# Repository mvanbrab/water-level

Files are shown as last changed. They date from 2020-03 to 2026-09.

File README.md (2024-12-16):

# Introduction
Here I share hardware and software about my **water-level** project,
whose purpose is to measure the water level in a water reservoir,
located under the ground.

This project actually has a predecessor. Enjoy reading about it in this [bit of history](doc/history.md).

# The transmitter
The first piece of hardware is a transmitter.
It measures the water level with a waterproof ultrasonic sensor and sends the measurement result as a JSON object via RS232 to a possibly connected receiver.

The positioning of this sensor in my project is described in the [physical setup](doc/physical.md).

Here are some [pictures](doc/pictures-transmitter.md) showing the transmitter in practice.

In the folder **hardware/transmitter** you'll find the hardware design as a [KiCad](https://www.kicad.org/) project.
Without Kicad installed, you can view
- [the schematic diagram as .pdf](../master/hardware/transmitter.pdf);
- [the copper layout of the printed circuit board](../master/hardware/transmitter_cu.pdf);
- [the component placement on the printed circuit board](../master/hardware/transmitter_silk.pdf).

The folder **software/WaterLevelTransmitter** is an [Arduino](https://www.arduino.cc/) sketch, containing the software of the transmitter part of the project.

Read more about this piece of software [here](doc/water-level-transmitter-software.md).

# The receiver
The second piece of hardware is the receiver.
It requests output from the transmitter and publishes is to whatever destination.

Here are some [pictures](doc/pictures-receiver.md) showing the receiver in practice.

In the folder **hardware/receiver** you'll find the hardware design as a [KiCad](https://www.kicad.org/) project.
Without Kicad installed, you can view
- [the schematic diagram as .pdf](../master/hardware/receiver.pdf);
- [the copper layout of the printed circuit board](../master/hardware/receiver_cu.pdf);
- [the component placement on the printed circuit board](../master/hardware/receiver_silk.pdf).

About the receiver hardware:
- the RS232 level converter is the same as used for the transmitter, this time it is powered from 3V3;
- the character-based LCD screen to connect is a 2 rows of 16 columns type, using an HD44780 driver, connected via I2C @ 3V3, but powered @ 5V;
- the processor board (chosen because of its WiFi connectivity) is a [ESP32 DevKitC](https://docs.espressif.com/projects/esp-idf/en/latest/esp32/hw-reference/esp32/get-started-devkitc.html)
 (with ESP32-WROOM-32D module).

The folder **software/WaterLevelReceivers** is contains a set of [Arduino](https://www.arduino.cc/) sketches, each containing a different software solution for the receiver part of the project.

Read more about this piece of software [here](doc/water-level-receiver-software.md).

# Connecting the transmitter with the receiver

| Transmitter | Receiver |
| --- | --- |
| GND (J1.2)  | GND (J1.3) |
| TXD (J1.4)  | RXD (J1.2) |
| RXD (J1.5)  | TXD (J1.1) |

# Lessons learned
[The temperature measurement](doc/ll01.md)

[Condensation on the sensor](doc/ll02.md)

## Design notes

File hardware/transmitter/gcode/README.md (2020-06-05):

Files here were added by Dylan and are derived from the Kicad project, using his tools for pcb creation.

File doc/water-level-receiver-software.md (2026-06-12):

# The WaterLevelReceiver software

## Operation

Every second, the program sends a single "?" character to the Serial2 port, at 115200 Baud.
Each "?" acts as a request for a new measurement to the connected transmitter.
If all's well, the transmitter will reply with a JSON output as document in the [transmitter documentation](water-level-transmitter-software.md).

The receiver will decode this JSON payload and can publish it to several destinations,
depending on the version of the program.
The supported destinations:

- the serial port accessible through the USB connection (at 115200 Baud);
- a character-based LCD display using the hd44780 chip;
- a locally hosted webpage;
- MQTT, in this case to a topic "home/regenput/state".

In addition, the program watches button input.
Currently, there is only one button defined:

- a button connected between GPIO12 and ground: controls LCD backlight (button closed = backlight on).

## Serial port output

Serial port output consists of:

- the temperature in numerical form;
- the volume in liters in numerical form;
- the volume as percentage in numerical form;
- a LOW indicator, only written if the level is low.

## LCD output

LCD output consist of:

- a representation of the volume as percentage in a bar graph;
- the volume as percentage in numerical form;
- the volume in liters in numerical form;
- a LOW indicator, only displayed if the level is low;
- a heartbeat indicator, changing between '*' and ' '.

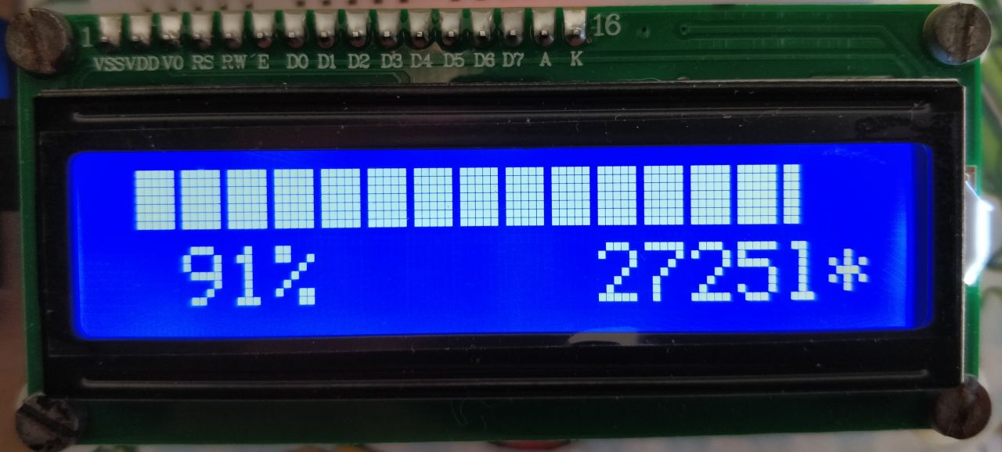
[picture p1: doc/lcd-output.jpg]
lcd-output


## HTTP output

HTTP output can consist of all information available in the serial port output.

Currently, a simple HTML representation shows:

- volume in liters, in a HTML meter element and as percentage (the LOW indicator is represented with red volume values) 
- temperature in °C (red in case of frost)

An example:

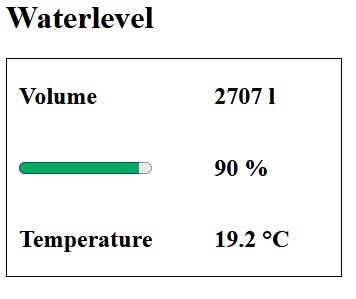
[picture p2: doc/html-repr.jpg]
html-representation


## MQTT output

An MQTT server is accessed via WiFi using the Arduino library 'EspMQTTClient'
and the output is published on a single topic "home/regenput/state" once per minute.

The payload is a JSON structure consisting of the fields:

- "t_C": the temperature;
- "vol_l": the volume in liters;
- "vol_percent": the volume as percentage;
- "low: the LOW indicator (true/false).

### Possibilities with MQTT

What follows is a non limiting list of examples.

#### Display data on Node-RED user interface elements

The Node-RED package `node-red-dashboard` has interesting nodes such as a **gauge**, allowing
to display output as shown below.

#### Export data to Influxdb for possible display using Grafana

The Node-RED contributed package `node-red-contrib-influxdb` has an **influxdb out** node, allowing to output data
to [Influxdb](https://www.influxdata.com/products/influxdb/).

These data can then be read by [Grafana](https://grafana.com/oss/), a great tool to visualise data.

#### Display the data in Home Assistant

For this purpose, the code publishes MQTT Discovery messages with single component discovery payload, understood by Home Assistant.

## Testing

Some DEBUG... preprocessor definitions are available to assist debugging the code.
They provide possibilities to output debug information and to provide fake input.

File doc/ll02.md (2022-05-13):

# Lesson learned: condensation on the sensor

## The problem

In november 2020 the measurement suddenly became unstable.

I had a look at the sensor and apparently there was so much condensation,
that some big drops of water where hanging at the bottom (active side) of the sensor.

Drying the sensor made the measurement stable again.

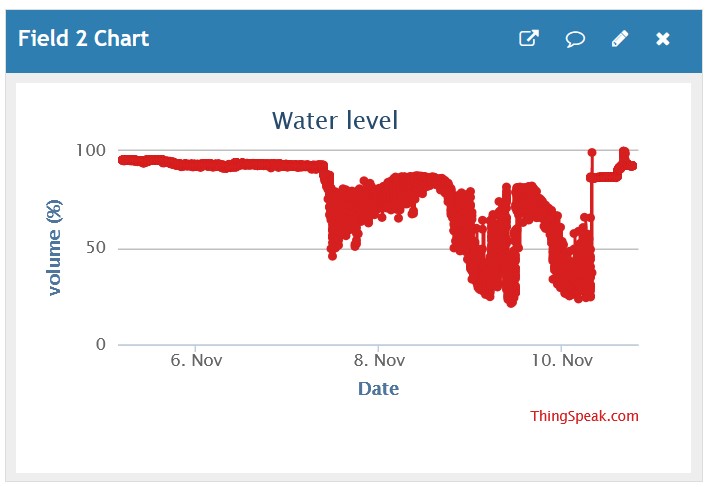
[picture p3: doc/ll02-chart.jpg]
chart


The reason for this condensation is obviously the combination of the following conditions:
* high vapor pressure
* bad ventilation
* cold sensor temperature 

## Attempt 1 (November 2020)

The idea behind this attempt is: give the water drops the possibility to drip off.

The sensor was rotated 90 degrees, putting the sensor surface vertically.
A reflection plate placed at 45 degrees ensures that the ultrasonic wave propagates in the correct direction.

As you can see, the mechanical setup reuses the original sensor mount.

Bottom view:

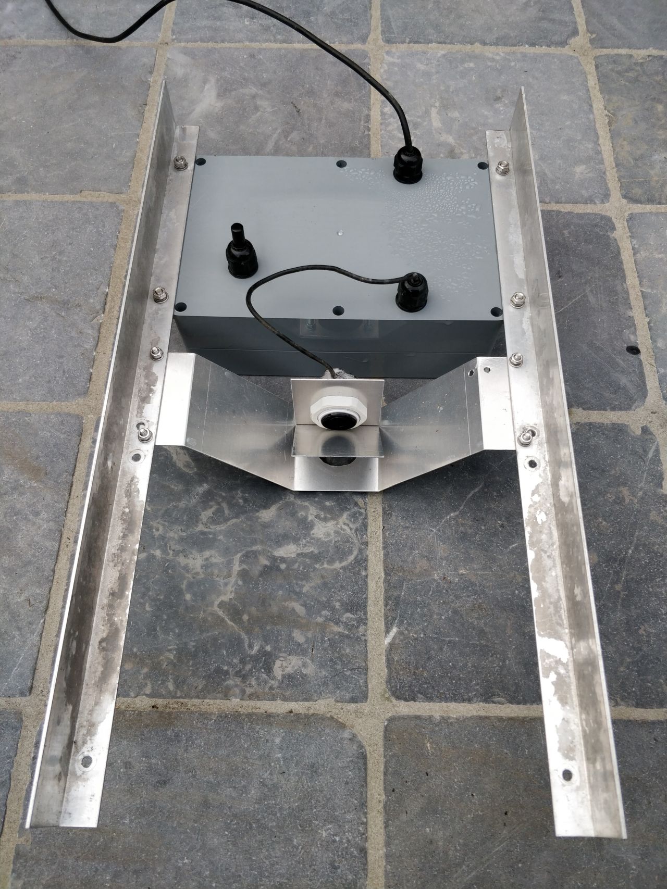
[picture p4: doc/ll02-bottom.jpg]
bottom


Detailed view:

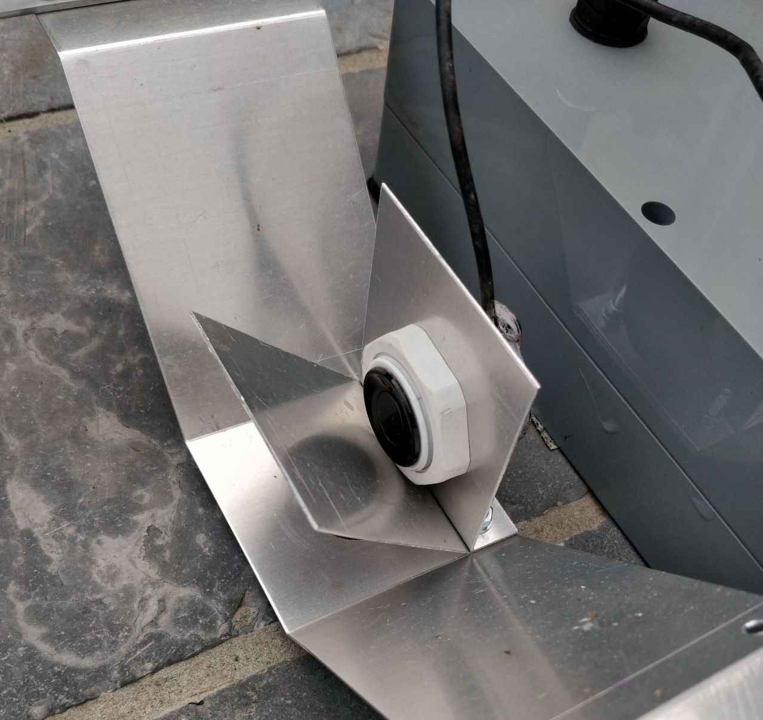
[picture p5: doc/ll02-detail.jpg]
detail


Installed:

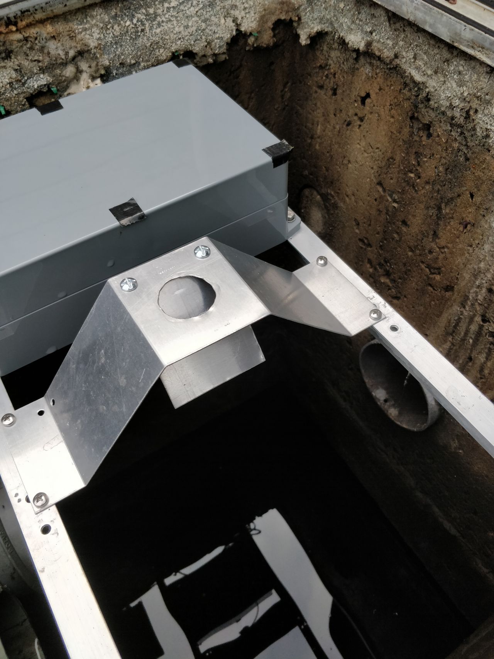
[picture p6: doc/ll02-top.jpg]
top


### Evaluation

The solution seemed to work well during winter.

However, due to frequent rainfall, the water level was continuously close to 100 %.

Around the middle of February, a dry period started end the water level started to fall.
The measurement however did not follow and somewhat later started to float heavily.

Inspection revealed that both the sensor and the reflection plate suffered from condensation again.
Drying them resulted in a stable measurement, until they suffered again from condensation later...

So clearly, this attempt is not a good solution

### Attempt 2 (March 2021)

The idea behind this attempt is: try to avoid low temperature at the sensor and the reflection plate, using isolation foam.

The sensor and the reflection plate were isolated as good as possible from the lid.

Sensor and reflection plate:

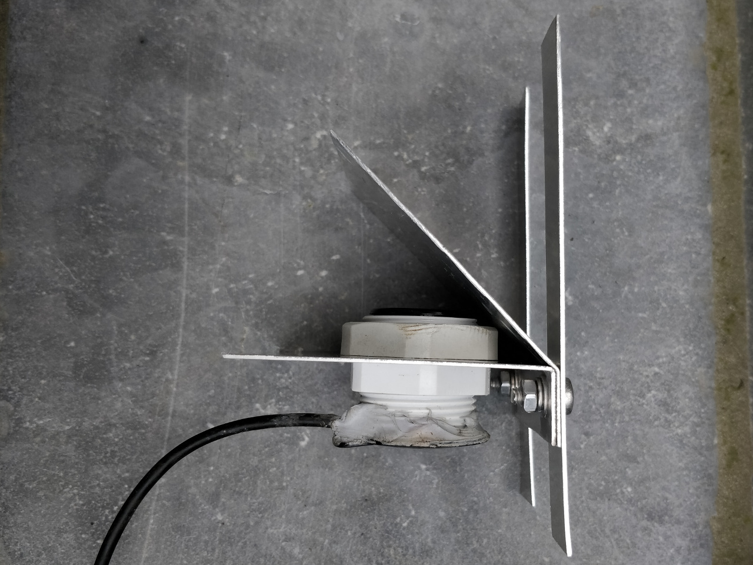
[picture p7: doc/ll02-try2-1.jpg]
attempt 2 sensor and reflection plate


Mounting in isolating box:

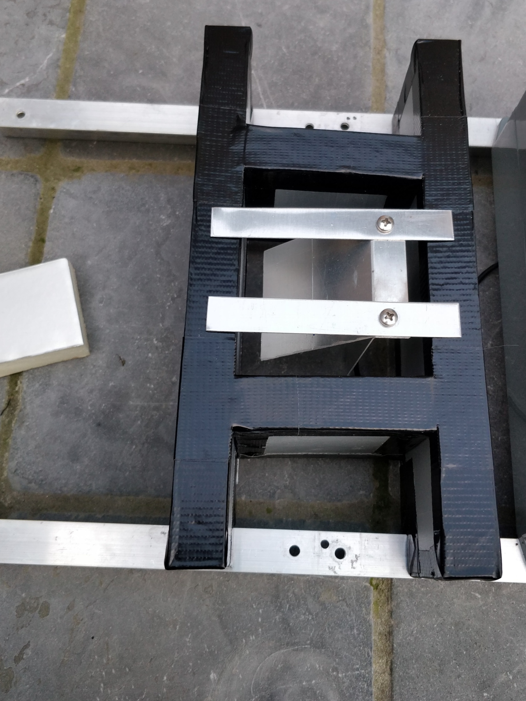
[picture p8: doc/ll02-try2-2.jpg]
attempt 2 mounting


Mounted:

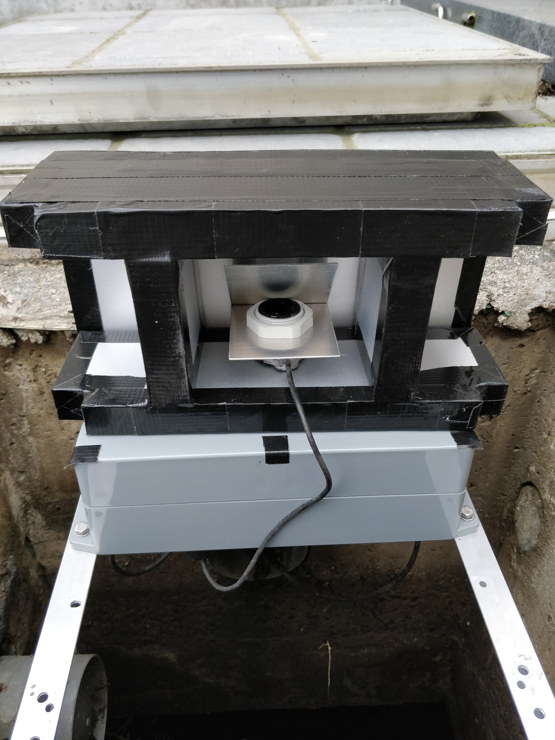
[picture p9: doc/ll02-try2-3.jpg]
attempt 2 mounted


Installed:

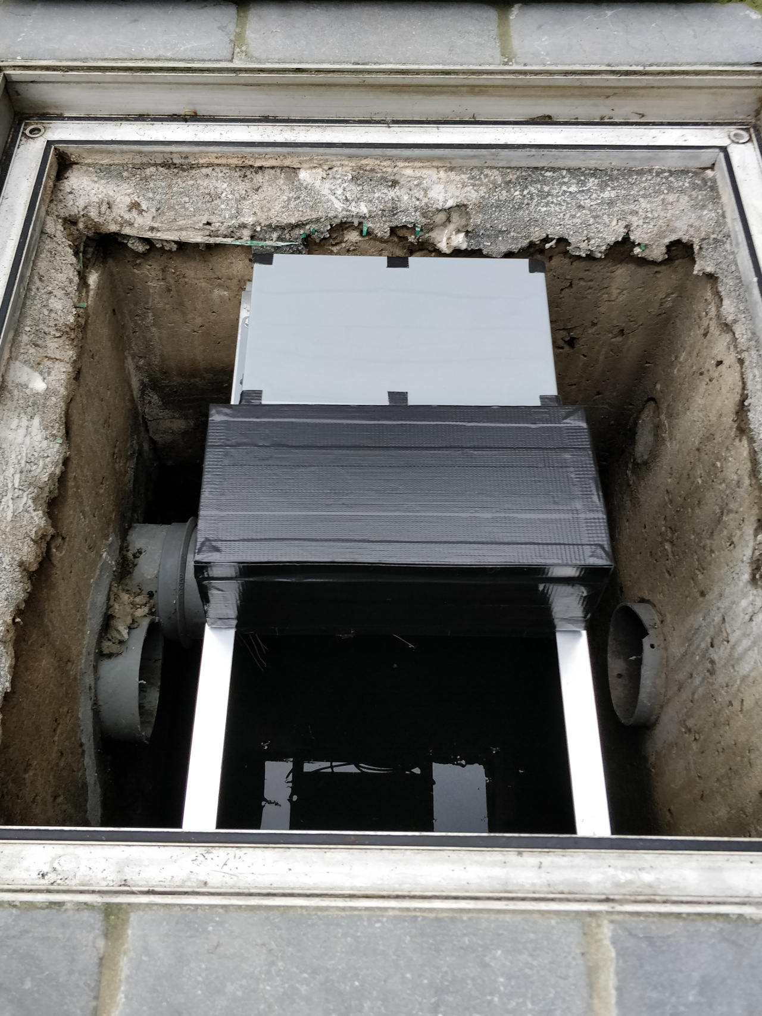
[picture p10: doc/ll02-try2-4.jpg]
attempt 2 installed


### Evaluation

The solution worked for a week, then: same problem. Changing weather conditions make it work well from time to time.
Drying sensor and reflection plate always helps instantaneously, but the problem keeps on returning...

### Attempt 3 (April 2021)

The input for this attempt is the observation that there is no condensation at the bottom of the plastic box.
Perhaps this is due to the small temperature rise due heat dissipation of the electronics.

The sensor was integrated in the bottom of the plastic box, and the voltage regulator (main source of dissipation)
was put on an aluminium frame, as close to the sensor as possible.
This can now become the hottest spot of the box and hopefully it will keep the sensor dry.

View inside the box:

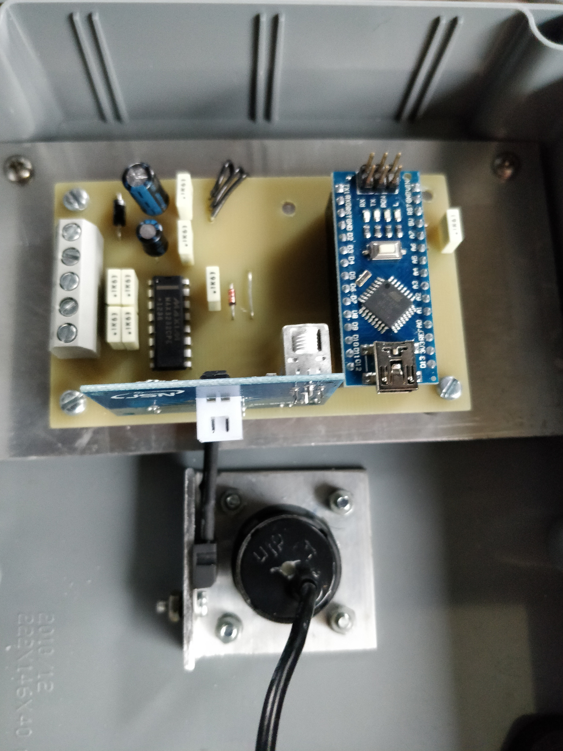
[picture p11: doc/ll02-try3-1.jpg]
attempt 3 inside


View of bottom of the box:

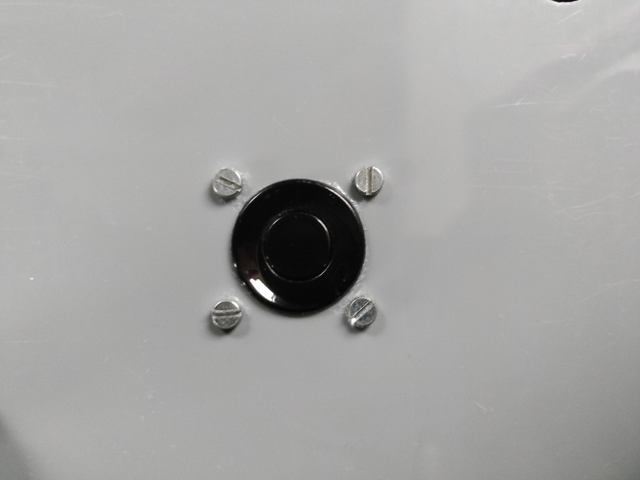
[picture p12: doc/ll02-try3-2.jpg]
attempt 3 bottom


Mounted, box open:

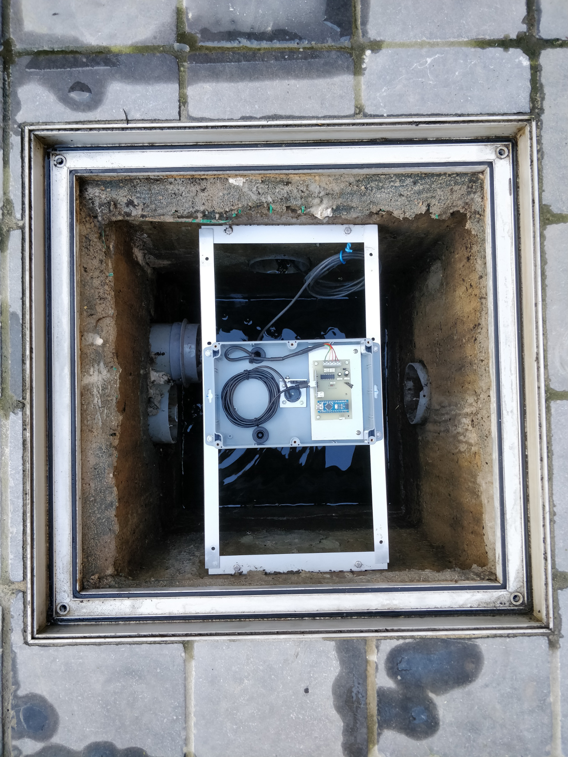
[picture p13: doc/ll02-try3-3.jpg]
attempt 3 mounted, box open


Installed:

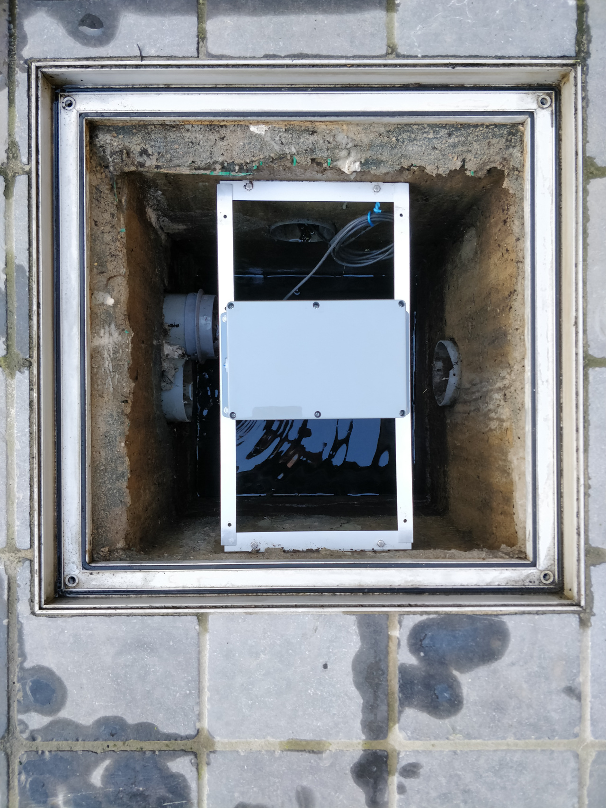
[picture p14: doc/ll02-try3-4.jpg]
attempt 3 installed


### Evaluation

More than one year later, today May 13th 2022, this attempt has not failed once. So I consider it a sufficient solution.

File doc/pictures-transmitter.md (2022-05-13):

# Pictures related to the transmitter

*Initial pictures shown below give an impression of the original implementation.
Some modifications were needed to solve the condensation issue explained in [this lesson learned](ll02.md).
Pictures including these modifications were copied at the bottom.*

## The printed circuit board

**Many thanks to my friend and colleague Dylan who was so kind to mill
this printed circuit board on his self-made milling machine!**

Bottom view before assembly

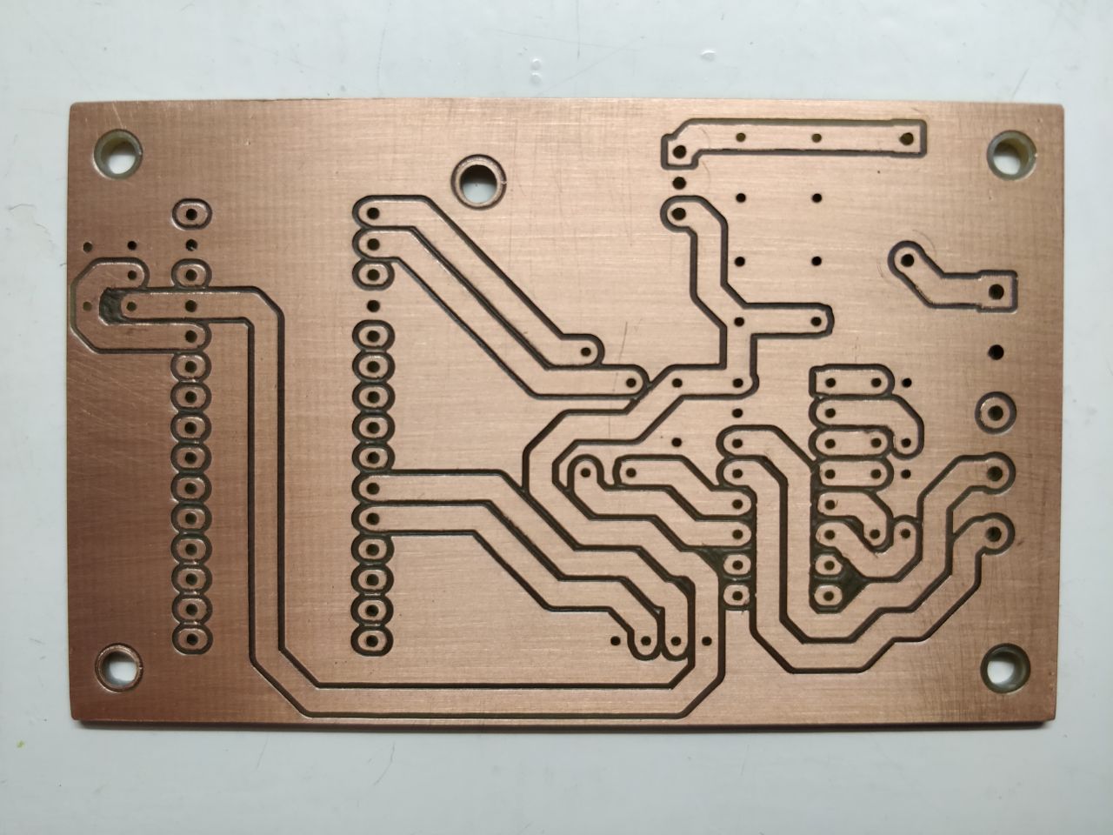
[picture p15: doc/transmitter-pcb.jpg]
pcb


Top view after assembly

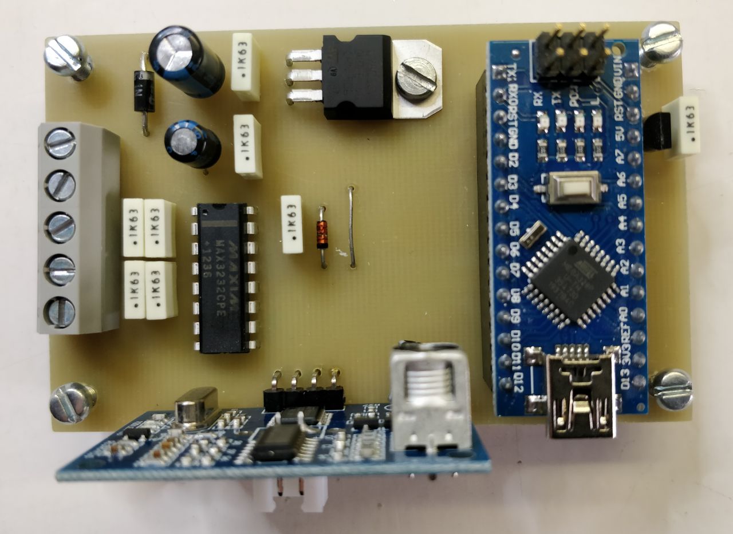
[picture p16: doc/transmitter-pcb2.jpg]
pcb2


3D view after assembly

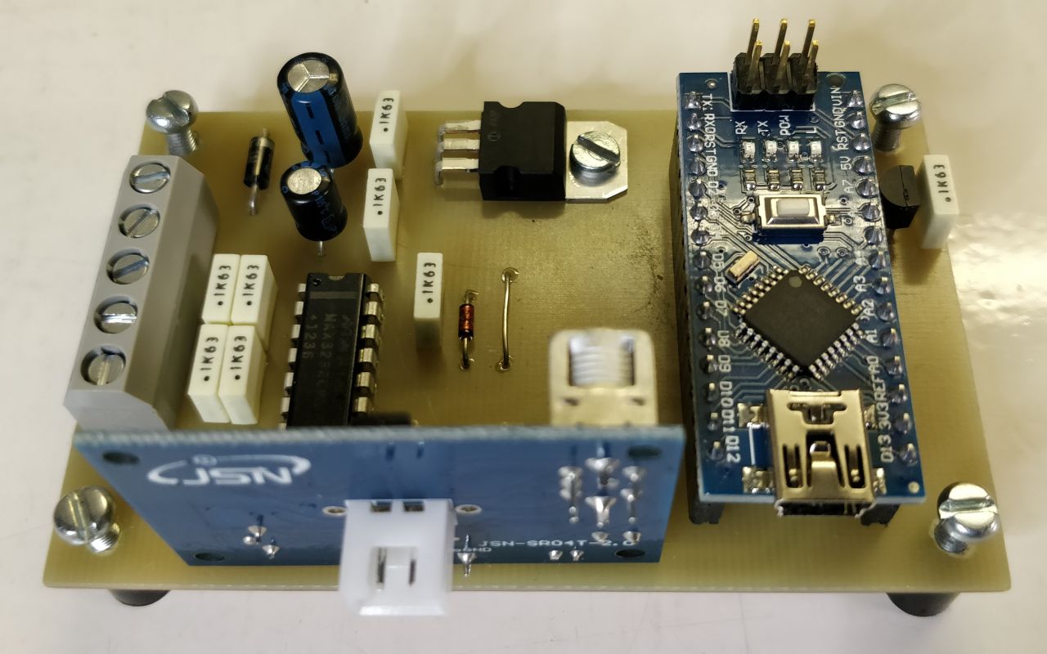
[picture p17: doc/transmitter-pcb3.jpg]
pcb3


## The sensor

The sensor and a cable gland, well suited for mounting

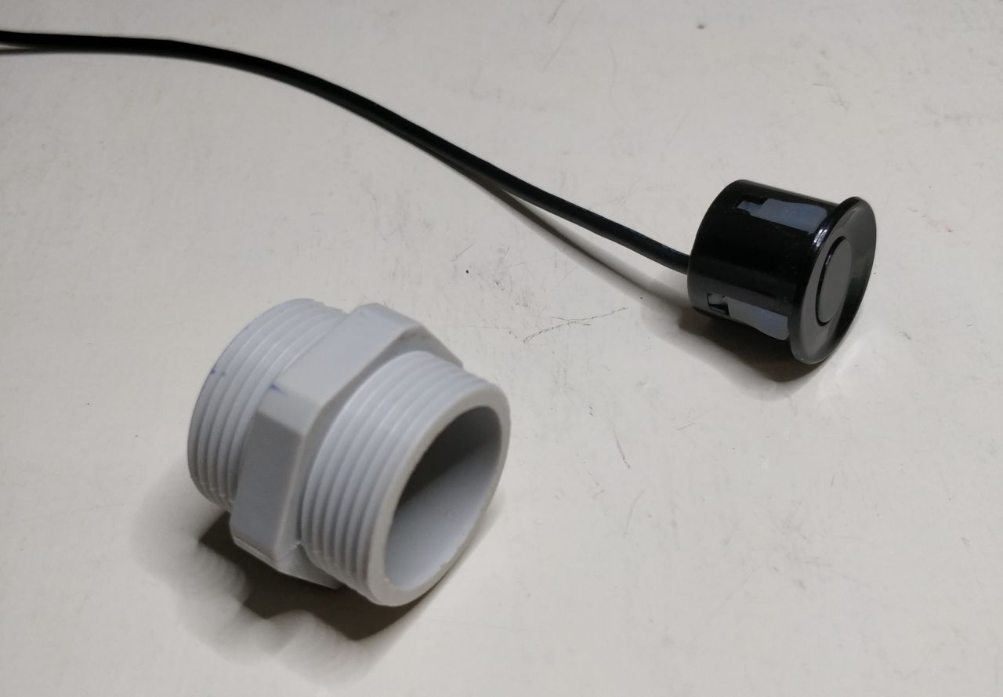
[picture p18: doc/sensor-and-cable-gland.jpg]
sensor


The sensor, mounted

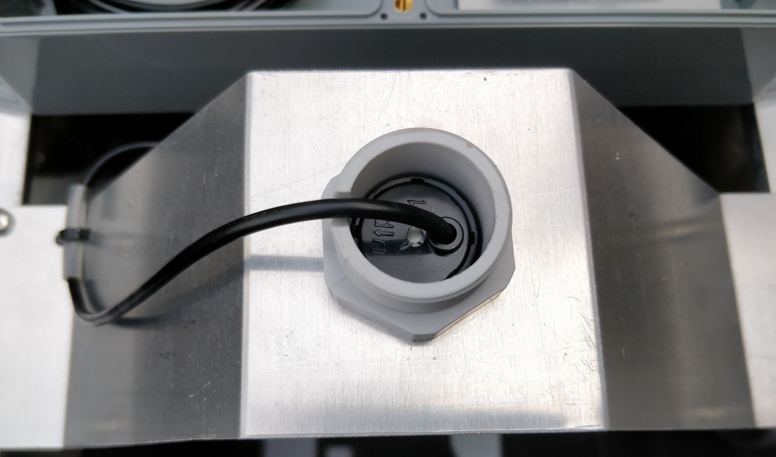
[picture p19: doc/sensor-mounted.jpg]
sensor2


The sensor, mounted and sealed.
To seal, the plastic lid of a pepper bottle was glued to the cable gland with some TEC7.

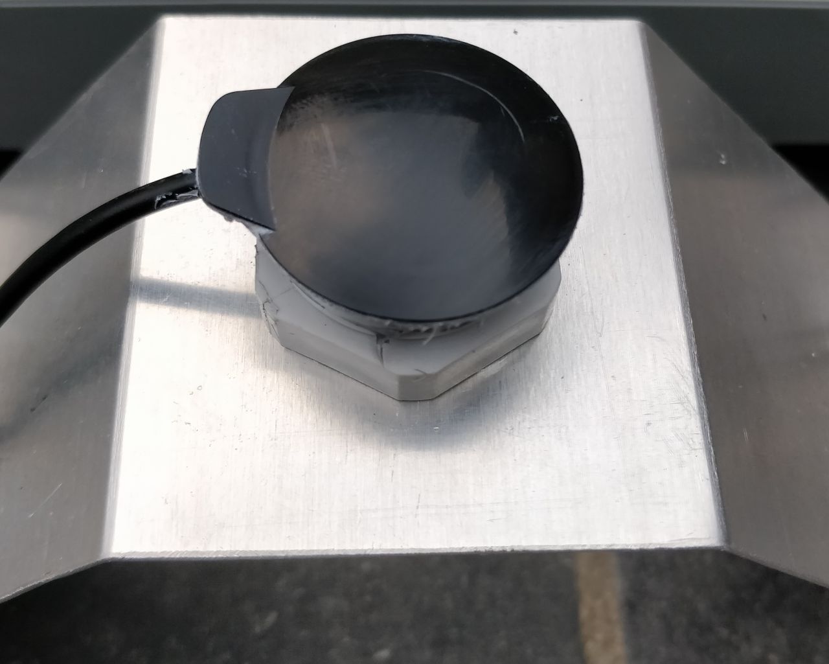
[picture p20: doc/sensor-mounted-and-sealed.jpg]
sensor3


## The assembly

The assembly, before closing

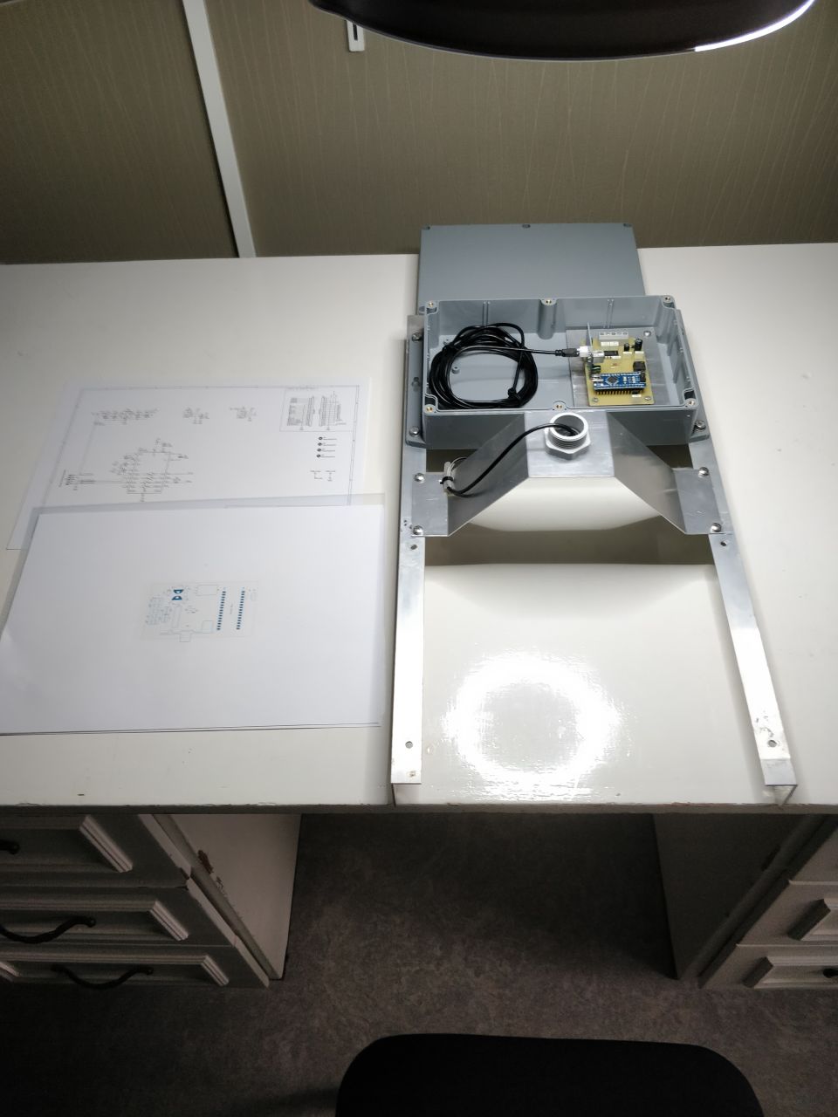
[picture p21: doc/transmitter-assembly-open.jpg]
assembly


A view at the bottom of the assembly.
Note that the aluminium angle brackets at the sides are a bit dirty;
they are reused from [the past](history.md).

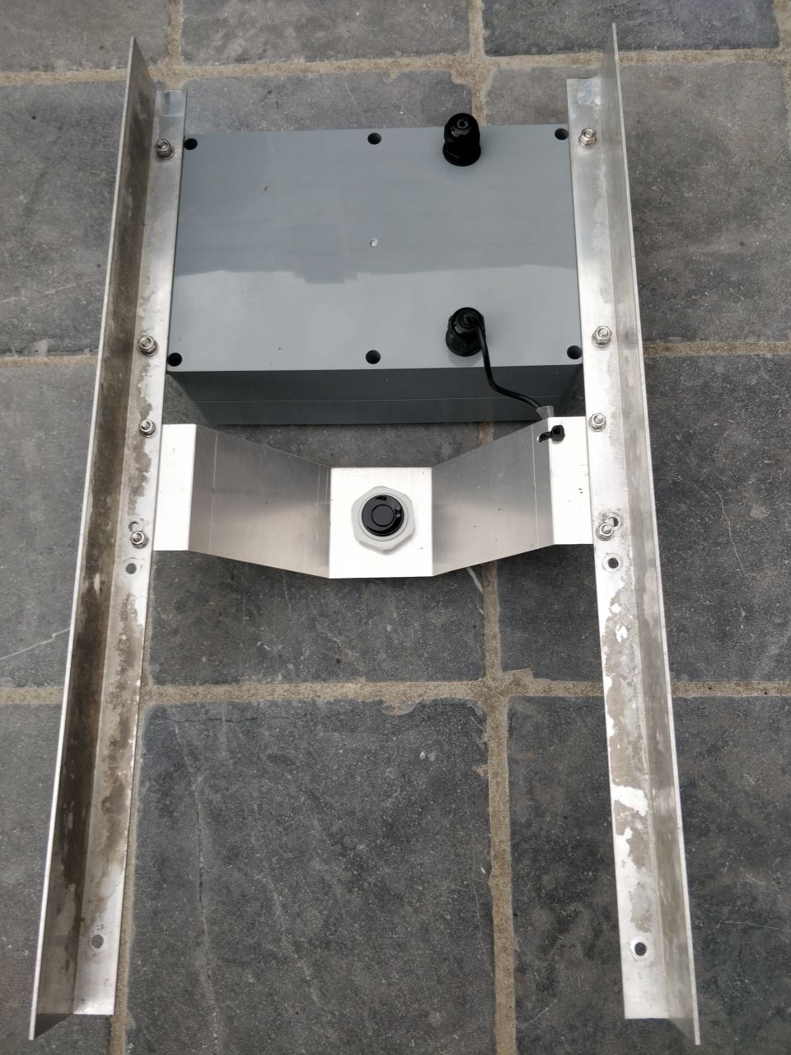
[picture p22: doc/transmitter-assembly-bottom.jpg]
assembly2


The manhole, prepared to contain the assembly.
Note the aluminium angle brackets placed against the walls of the manhole
and the cable that comes in via the pipe.

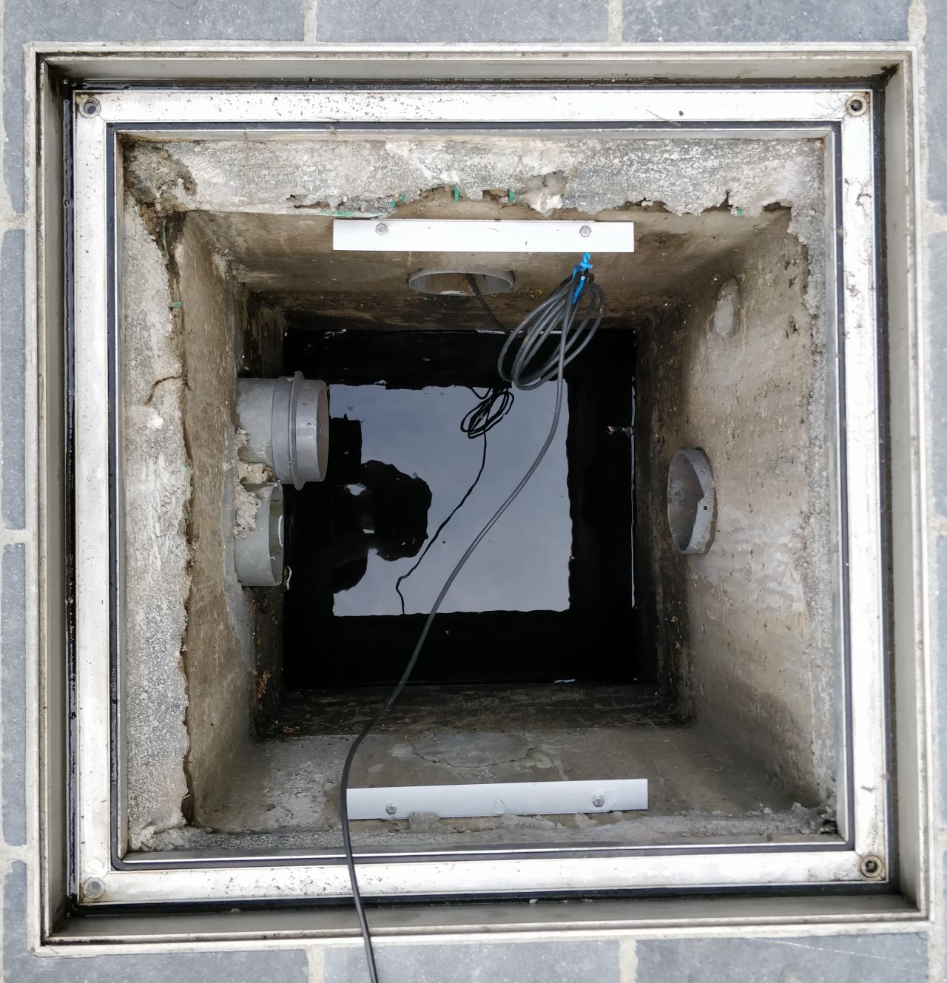
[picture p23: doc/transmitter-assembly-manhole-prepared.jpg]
assembly3


And finally, the end result.

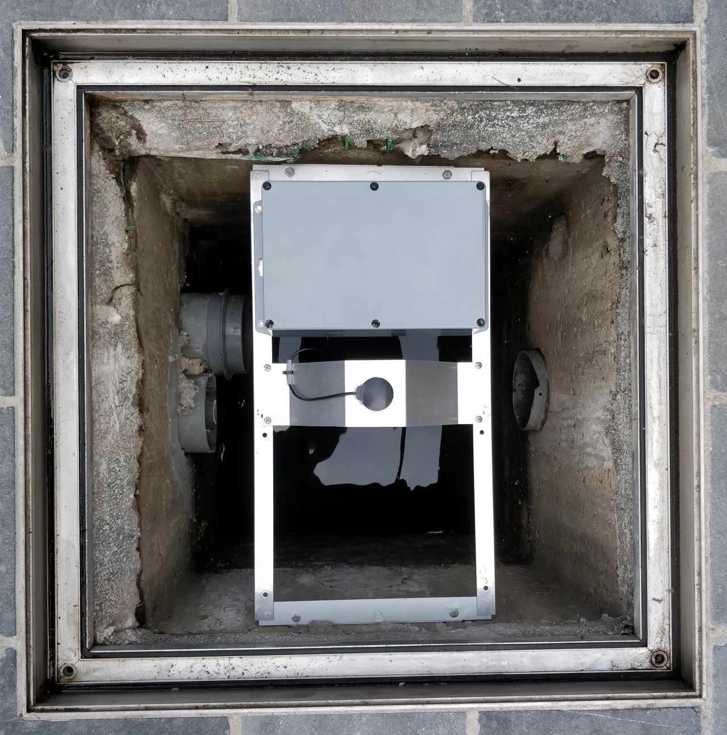
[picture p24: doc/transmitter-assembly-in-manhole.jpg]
assembly4


Lid closed, job done!

lid

## Updated pictures (after modification for the condensation issue)

Top view after assembly, including the mounted sensor

attempt 3 inside

A view at the bottom of the box

attempt 3 bottom

The assembly, before closing

attempt 3 mounted, box open

The assembly, closed

attempt 3 installed

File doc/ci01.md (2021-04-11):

# Current issue: condensation on the sensor

## The problem

In november 2020 the measurement suddenly became unstable.

I had a look at the sensor and apparently there was so much condensation,
that some big drops of water where hanging at the bottom (active side) of the sensor.

Drying the sensor made the measurement stable again.

chart

The reason for this condensation is obviously the combination of the following conditions:
* high vapor pressure
* bad ventilation
* cold sensor temperature 

## Attempt 1 (November 2020)

The idea behind this attempt is: give the water drops the possibility to drip off.

The sensor was rotated 90 degrees, putting the sensor surface vertically.
A reflection plate placed at 45 degrees ensures that the ultrasonic wave propagates in the correct direction.

As you can see, the mechanical setup reuses the original sensor mount.

Bottom view:

bottom

Detailed view:

detail

Installed:

top

### Evaluation

The solution seemed to work well during winter.

However, due to frequent rainfall, the water level was continuously close to 100 %.

Around the middle of February, a dry period started end the water level started to fall.
The measurement however did not follow and somewhat later started to float heavily.

Inspection revealed that both the sensor and the reflection plate suffered from condensation again.
Drying them resulted in a stable measurement, until they suffered again from condensation later...

So clearly, this attempt is not a good solution

### Attempt 2 (March 2021)

The idea behind this attempt is: try to avoid low temperature at the sensor and the reflection plate, using isolation foam.

The sensor and the reflection plate were isolated as good as possible from the lid.

Sensor and reflection plate:

attempt 2 sensor and reflection plate

Mounting in isolating box:

attempt 2 mounting

Mounted:

attempt 2 mounted

Installed:

attempt 2 installed

### Evaluation

The solution worked for a week, then: same problem. Changing weather conditions make it work well from time to time.
Drying sensor and reflection plate always helps instantaneously, but the problem keeps on returning...

### Attempt 3 (April 2021)

The input for this attempt is the observation that there is no condensation at the bottom of the plastic box.
Perhaps this is due to the small temperature rise due heat dissipation of the electronics.

The sensor was integrated in the bottom of the plastic box, and the voltage regulator (main source of dissipation)
was put on an aluminium frame, as close to the sensor as possible.
This can now become the hottest spot of the box and hopefully it will keep the sensor dry.

View inside the box:

attempt 3 inside

View of bottom of the box:

attempt 3 bottom

Mounted, box open:

attempt 3 mounted, bow open

Installed:

attempt 3 installed

### Evaluation

Currently under investigation. So far, so good!

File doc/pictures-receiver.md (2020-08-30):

# Pictures related to the receiver

## The printed circuit board

**Many thanks to my friend and colleague Dylan who was so kind to mill
this printed circuit board, as he did for the transmitter earlier!**

Bottom view before assembly

pcb

Top view after assembly.
Note that on the ESP32-DevKitC V4 capacitor C15 was removed, as
[documented here](https://docs.espressif.com/projects/esp-idf/en/v3.3/get-started/get-started-devkitc.html#note-on-c15).

pcb2

Wires connected and operational.
Note the processor board receives power from USB here, so J2 is not connected.

pcb3

## The assembled box

The box (open).

box1

The box (closed).

box2

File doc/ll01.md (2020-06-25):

# Lesson learned: the temperature measurement

## The problem

In the prototype, the temperature measurement seemed quite accurate.

However, in the final setup, the measurement suffers from self-warming
of the electronics in the waterproof box containing the transmitter.

This can be seen from the following graph, copied from ThingSpeak.
The graph starts at power on and shows measurements at one minute intervals.
One can see a rise of the measured temperature of about 5°C during the warming up period,
while the ambient temperature can be assumed as good as constant...

temperature-rise-in-box

It's important to find a solution for this, because we're using the measured
temperature to correct the water level measurement, which depends on the speed of sound,
which on its turn depends on the temperature...

## The solution

The obvious solution is to place the temperature sensor (U2) outside the box.
This needs to be done carefully, because the box needs to be waterproof.

I unmounted U2, extended its pins with wires,

prepare-sensor-1

put some heat shrink on it

prepare-sensor-2

and mounted it at the copper size of the printed circuit board.

prepare-sensor-3

I placed an extra gland in the bottom of the box,
matching the new position of U2 and mounted the printed circuit board,
so that U2 appeared through the gland.

sensor-in-gland-1

I prepared a metal pipe with a diameter of 8 mm, open at one side

sensor-pipe-1

and closed at the other side.

sensor-pipe-2

I put some thermal joint compound on U2

sensor-in-gland-2

and finally, I put the pipe over U2 and tightened the gland.

sensor-in-gland-3

The new bottom view of the box is as follows.

new-bottom-view

A new observation of the temperature measurement during warming up of the box
results in the following diagram.

Apparently, there is still some drift, but now it is limited to about 1 °C.
The resulting drift might be due to some residual warming of the sensor,
or to temperature dependency of the A/D-converter, whose reference voltage is the 5V supply voltage...

Anyway, this drift is acceptable for our purpose... Mission accomplished!

temperature-rise-sensor-outside

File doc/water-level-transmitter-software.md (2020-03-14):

# The WaterLevelTransmitter software

## Operation

The program waits for serial input, expected at 115200 Baud.
The contents of the serial input don't care.

As soon as serial input is received, one measurement is executed.
First, the time for an ultrasonic burst to travel from the sensor to the water surface and back is measured.
Next, from this time, the distance (and derived variables) are calculated, taking into account the ambient temperature.
The result is packaged in a [JSON](https://tools.ietf.org/html/rfc7158) text, making it ready for human as well as machine consumption.

Finally, any pending serial input that might be received in the mean time, is flushed and after a short delay, new serial input is expected, restarting the entire cycle.

## The JSON output

An example:
```
{
  "t_C": 21.78,
  "distance_m": 0.790,
  "height_m": 1.340,
  "vol_l": 2680,
  "vol_percent": 89.35,
  "low": false
}
```

Another example, this time with an active *low* indication:
```
{
  "t_C": 22.27,
  "distance_m": 1.968,
  "height_m": 0.162,
  "vol_l": 325,
  "vol_percent": 10.83,
  "low": true
}
```

Properties in the JSON object:

| property name | value |
| --- | ----- |
| "t_C" | temperature, in °C |
| "distance_m" | distance from sensor to water surface (d), in meter |
| "height_m" | water level, height measured from the bottom (x), in meter |
| "vol_l" | volume of available water, in liter |
| "vol_percent" | volume of available water, % of maximum volume |
| "low" | boolean; true means water level below safety threshold |
 
## Configuring the code
The following constants in the code of WaterLevelTransmitter.ino can be adapted to a specific physical setup.
See also [the physical setup](physical.md).

```
// H1 (meter)
#define H1 1.50
// H2 (meter)
#define H2 0.68
// H3 (meter)
#define H3 0.05
// V (liter)
#define V 3000
// X_MIN (meter)
#define X_MIN 0.25
// X_MIN (meter)
#define X_MIN 0.25
```

## Testing
This program can be easily tested by connecting the Arduino Nano's USB port to a terminal program, such as the Serial Monitor
included in the Arduino IDE.

Set the baudrate to 115200.

Set line ending mode to Newline.

Every push on the *Send* button, even with an empty input line, should result in a JSON text (as illustrated) returned by the board.

## References
* http://www.beckymarshall.com/depthSensor.html (Experiment 2)
  * I based the bit banging code to control the JSN-SR04T-2.0 ultrasone distance detector upon her well working experimental code.
* https://en.wikipedia.org/wiki/Speed_of_sound
  * I used the given formula for calculating the speed of sound as a function of temperature in °C (c_air = 331.3 + 0.606 * t_C) from this reference.

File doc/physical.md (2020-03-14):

# Physical setup

## Description of the situation
The following drawing illustrates the physical setup.



The reservoir is located under the ground.

On top of the reservoir, there is a manhole.

The water, harvested from the roof of my house, enters the manhole via the supply pipe.

The drain pipe evacuates the excess water.

## Limits applicable to the sensor we're using
The JSN-SR04T-2.0 defines a measurement range from 20 cm to 600 cm, with a measurement angle of 75 degrees.

If we want to measure correctly up to and including the situation where the water level
reaches the top of the drain pipe, we'll have to choose the height of the sensor so that (inequality 1):
```
H4 - H3 > 20 cm
```
That is possible in my setup.

If we want to measure correctly for an empty reservoir, we'll have to verify that (inequality 2):
```
H1 + H2 - H3 < 600 cm
```
That is not a problem in my setup.

Now, what about the third limit of the sensor, the measurement angle?
Does it mean that
(a) objects with a surface perpendicular to the emitted signal can be detected within this angle
or
(b) objects with a surface not perpendicular to the emitted signal but within this angle will disturb the measurement?

I tested and luckily it's not (b); otherwise the walls of the manhole would have made measurements impossible...

## Formulas
Water level (or height, distance from the bottom of the reservoir):
```
x = H1 + H2 - H3 - d
```
(where d is the measured distance)

Water volume (% of fraction of V):
```
x(rel) = x / H1 * 100%
```
(for x <= H1; we consider the reservoir full, when the water level reaches the bottom of the manhole)

Water volume in the reservoir:
```
v = x / H1 * V
```
(also for x <= H1)

## Dimensions (in my setup)

| dimension | value |
| --- | ----- |
| H1 | 1,50 m |
| H2 | 0,68 m |
| H3 | 0,05 m |
| H4 | 0,30 m |
| V | 3000 l |

Additionally, one can define a *water level safety threshold X_MIN* as the water level or height x
below which it isn't safe to continue water consumption using a pump.

In my setup X_MIN = 0,25 m.

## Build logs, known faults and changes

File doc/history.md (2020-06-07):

# A bit of history
First of all, I owe you a little bit of history.

## The good old days
In the so-called good days, measuring the water level was as easy as opening the lid
and putting a marked stick with markers in the water.

## The bricklayer
But then, the bricklayer came to build my new terrace.
He proposed a very nice new lid.
Very beautiful indeed and fastened with bolts.
But: not quickly removable!

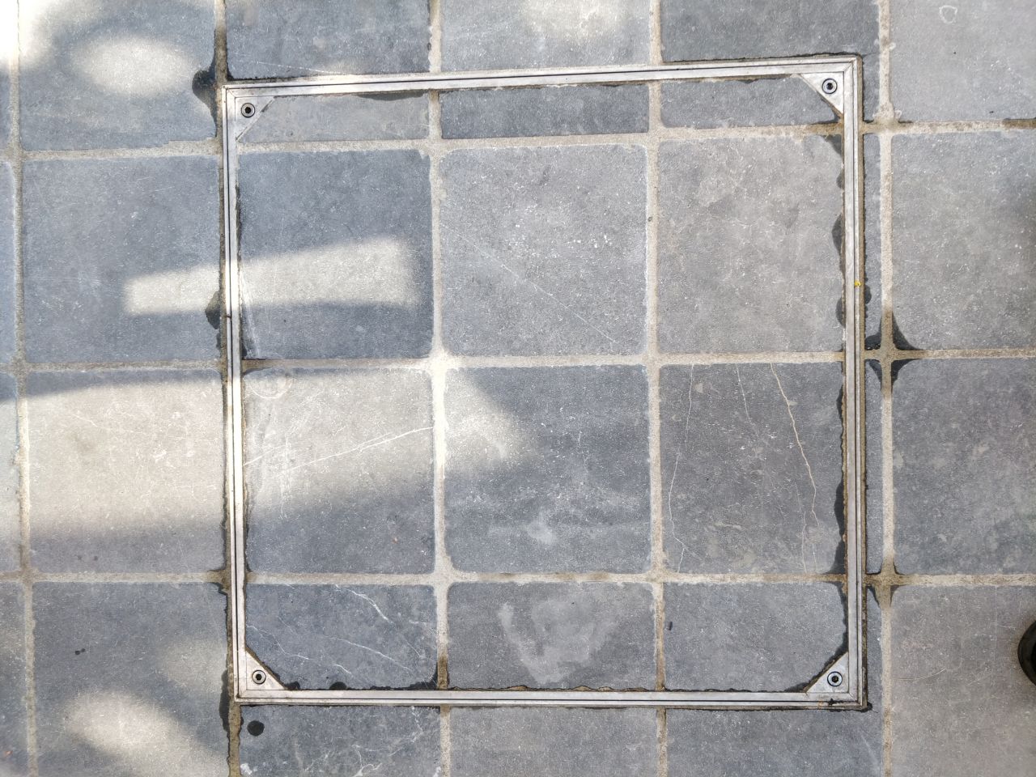
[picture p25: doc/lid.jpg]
lid


## The easy solution with pulleys
Being rather conservative, I thought of a simple mechanical solution.
I made a solution with a rotating shaft, two pulleys, a float, a counterweight
and a multi-turn potentiometer.

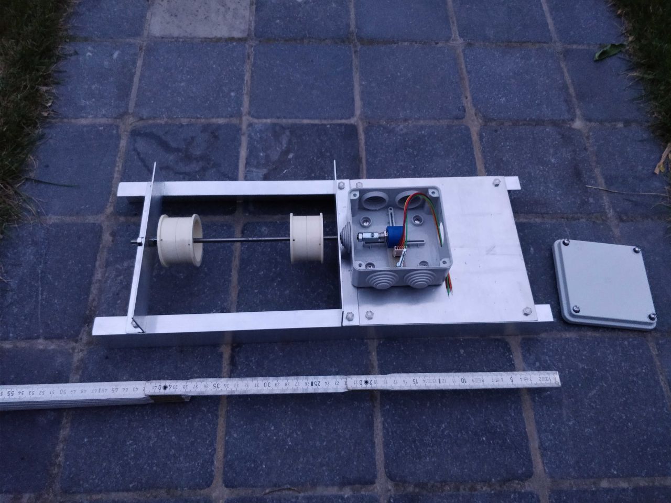
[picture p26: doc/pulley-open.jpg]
pulley-open


I had to dimension the diameter of the pulleys so that the travel of the float
from an empty to a full reservoir would correspond to a little bit less than
the 10 turns range of the potentiometer.

The only thing left to do, was to pull a cable through the water pipe, via the roof, into my house.

From then on, I could calculate the water level from the resistance measured between two wires
of that cable. I measured simply with an ohm meter. 0 ohm corresponded to empty; 10 k-ohm corresponded to full.

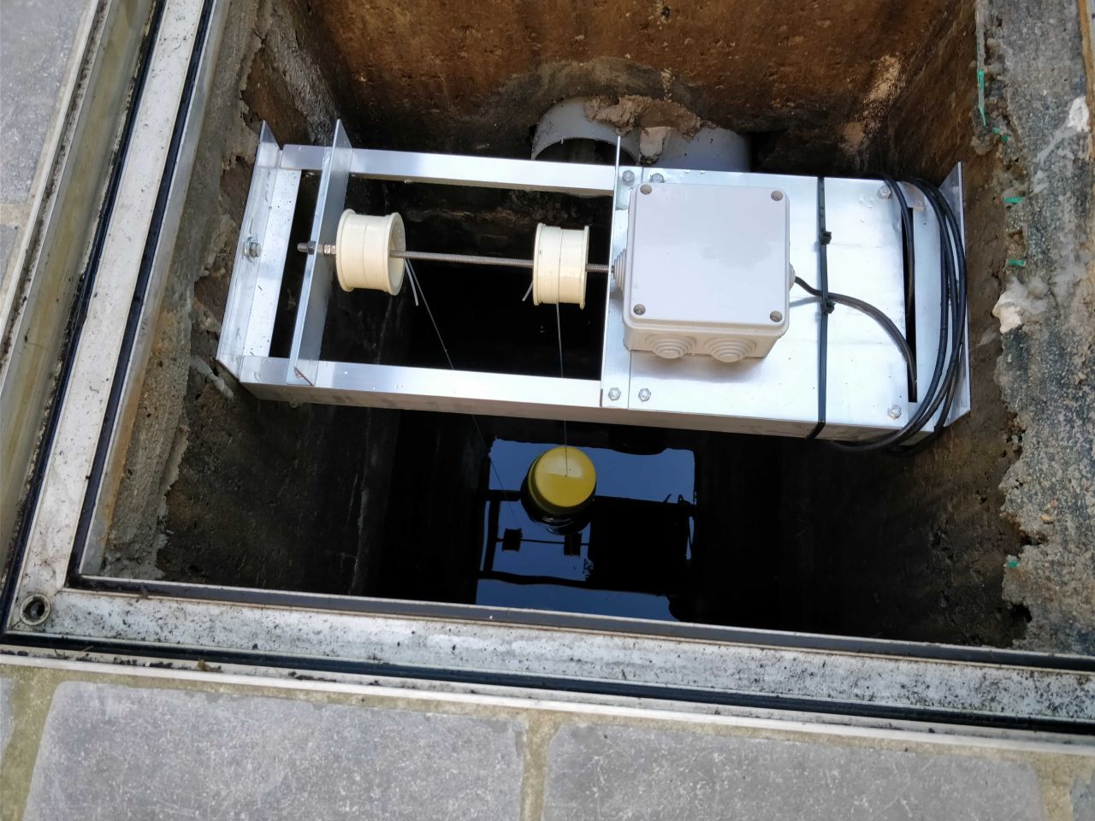
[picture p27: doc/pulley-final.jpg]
pulley-final


If I ever had the time, I could read the analog value with a small embedded system,
and present the result in a nice way...

## The end
Unfortunately, it never got that far. The setup suffered from the moisture in the air above the water.
The plastic box was not sufficiently watertight where the shaft entered the box.
As a result: the potentiometer's runner stopped making contact due to oxidation and the ohm meter indicated infinite...
And that was the end of the easy solution...

## And then...
I got inspired by an old friend and ex-colleague, Koen, who solved this problem with an ultrasonic distance sensor.
I had already found out that the HC-SR04, an ultrasonic sensor well known to Arduino users, was not suited for this task,
because it is not waterproof.
But Koen found a waterproof alternative: the JSN-SR04T-2.0. This sensor is also used as a parking sensor in cars.

And then this project was born!
I ended up with my own implementation, in a different setup compared to Koen's:
- I could use wired communications, over the cable that was installed earlier.
- I could provide low voltage power, over the same cable.
- The physical situation in the area below the lid was different.

Enjoy further reading!

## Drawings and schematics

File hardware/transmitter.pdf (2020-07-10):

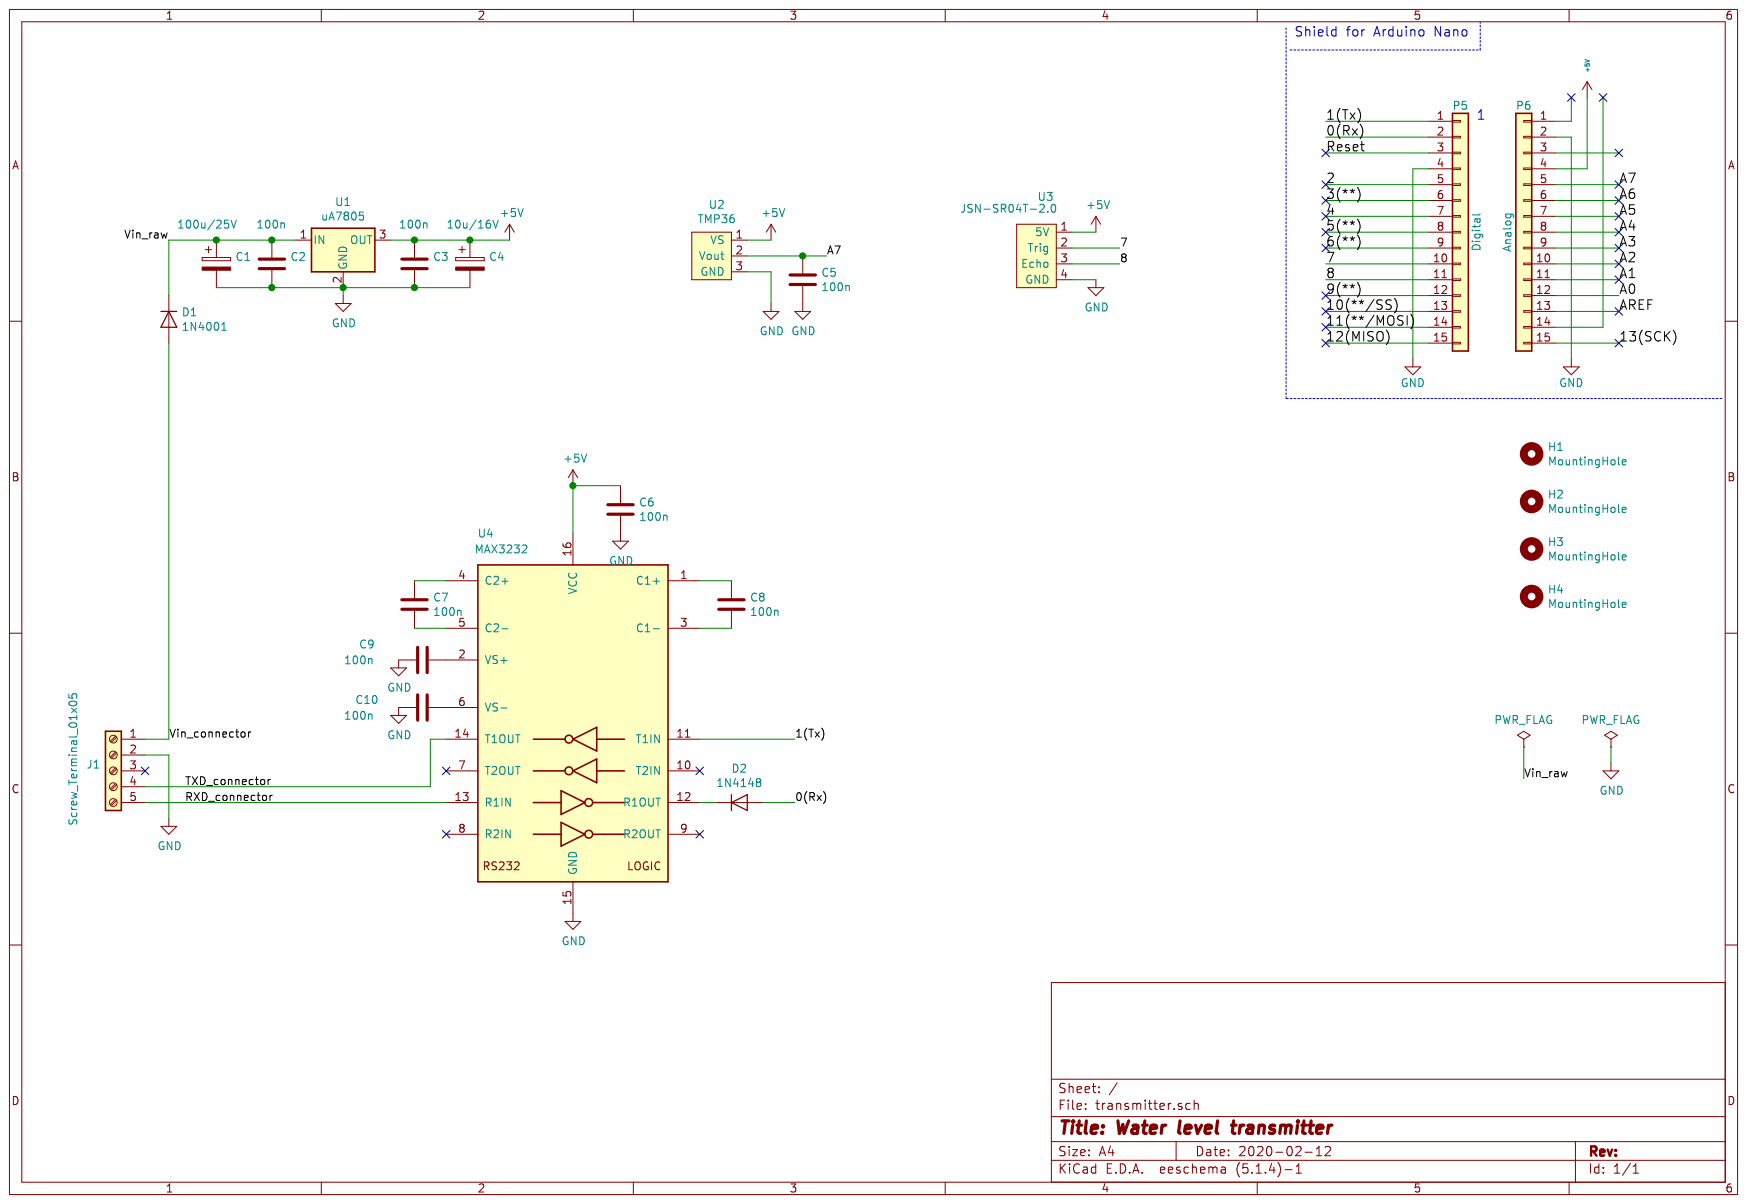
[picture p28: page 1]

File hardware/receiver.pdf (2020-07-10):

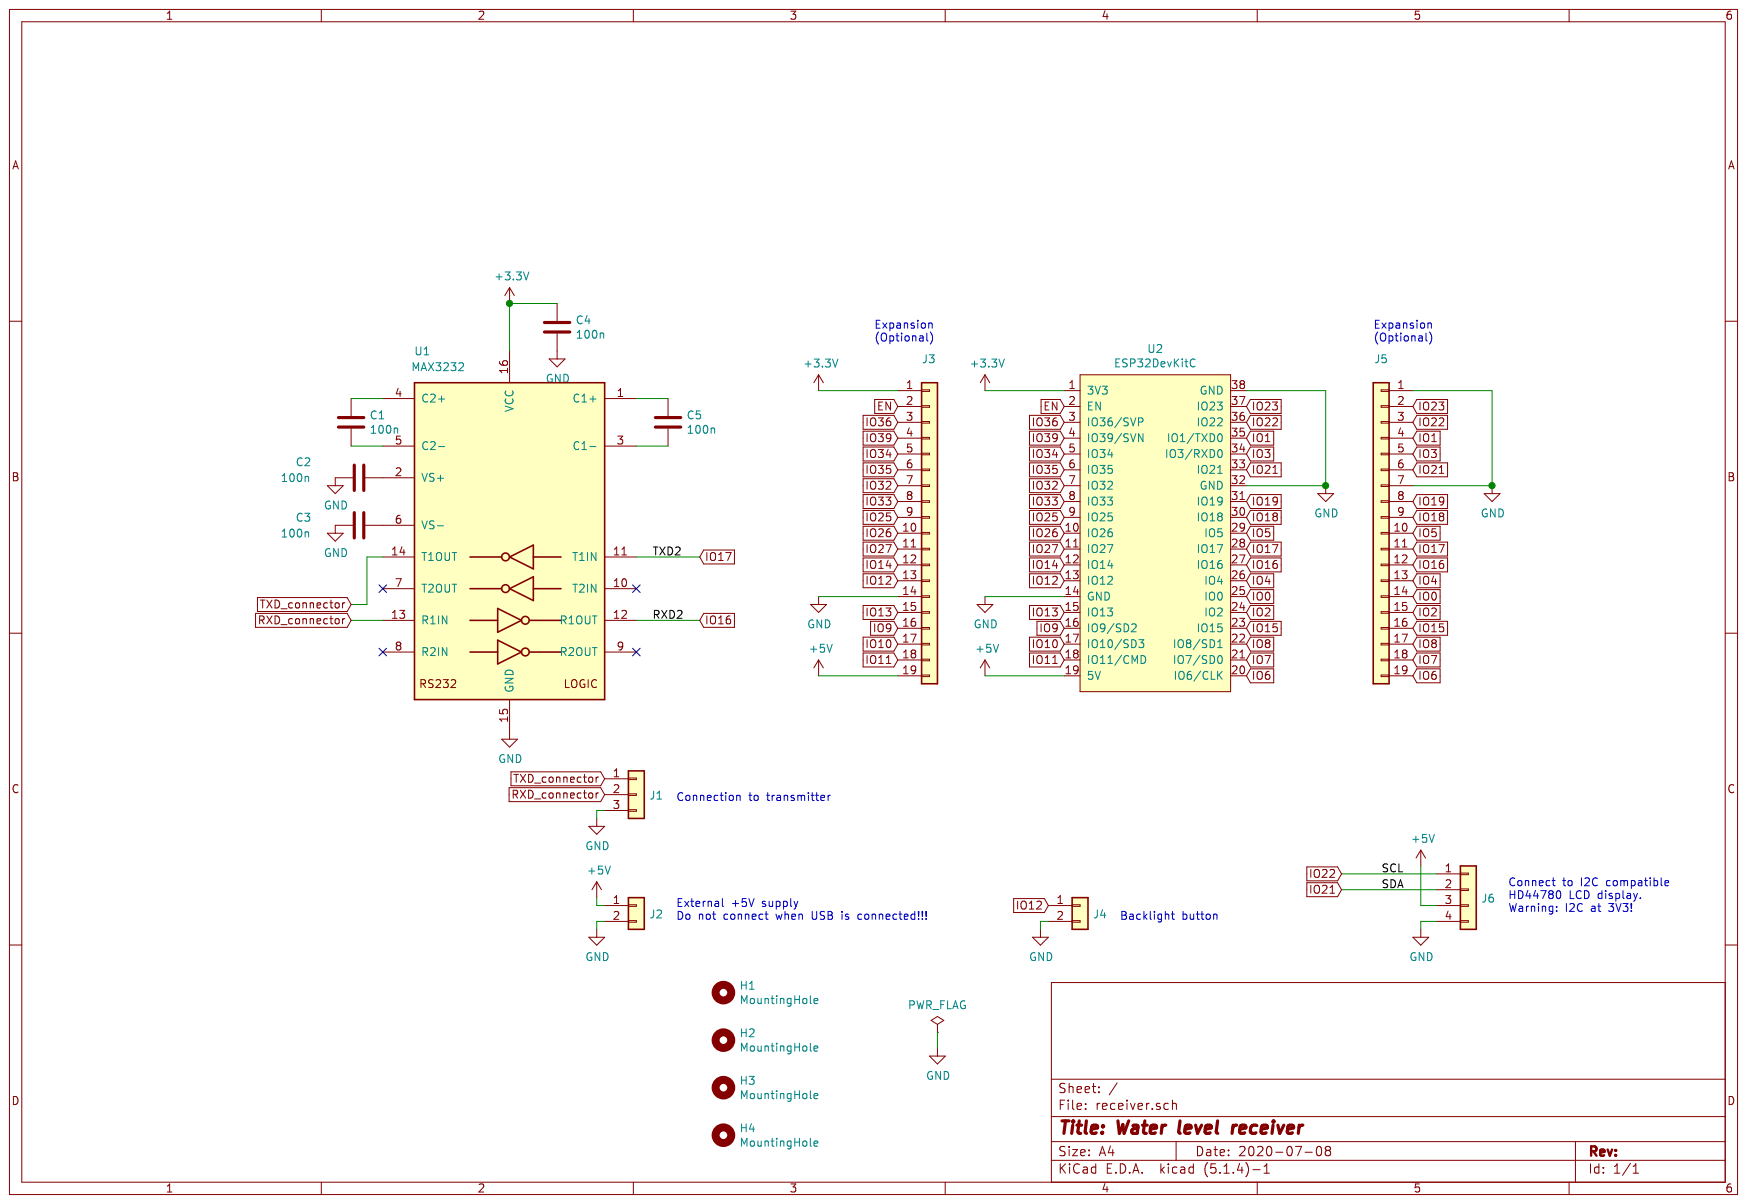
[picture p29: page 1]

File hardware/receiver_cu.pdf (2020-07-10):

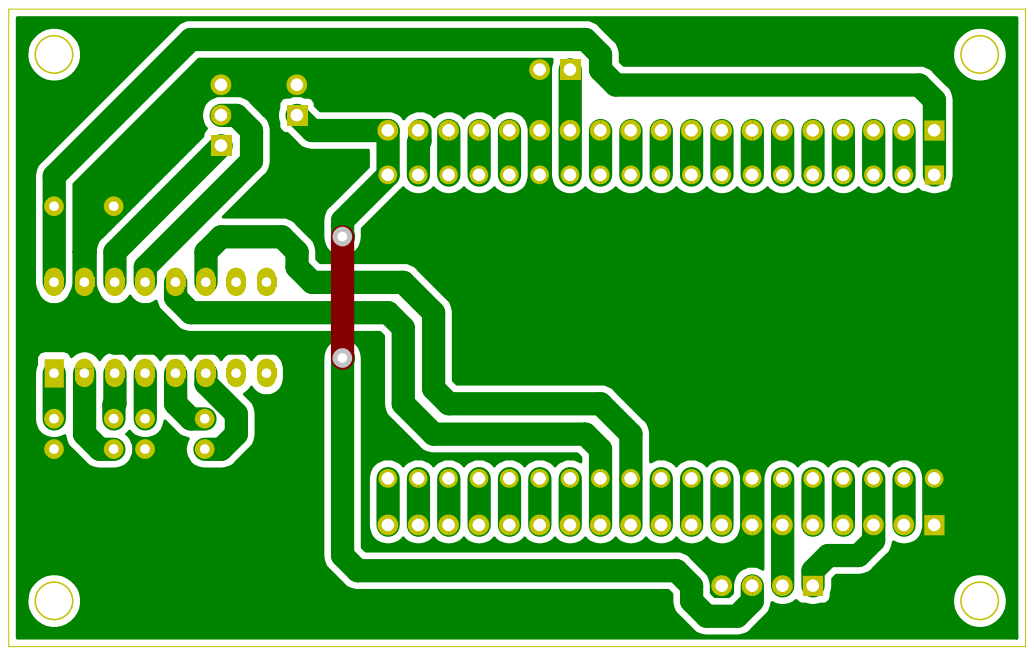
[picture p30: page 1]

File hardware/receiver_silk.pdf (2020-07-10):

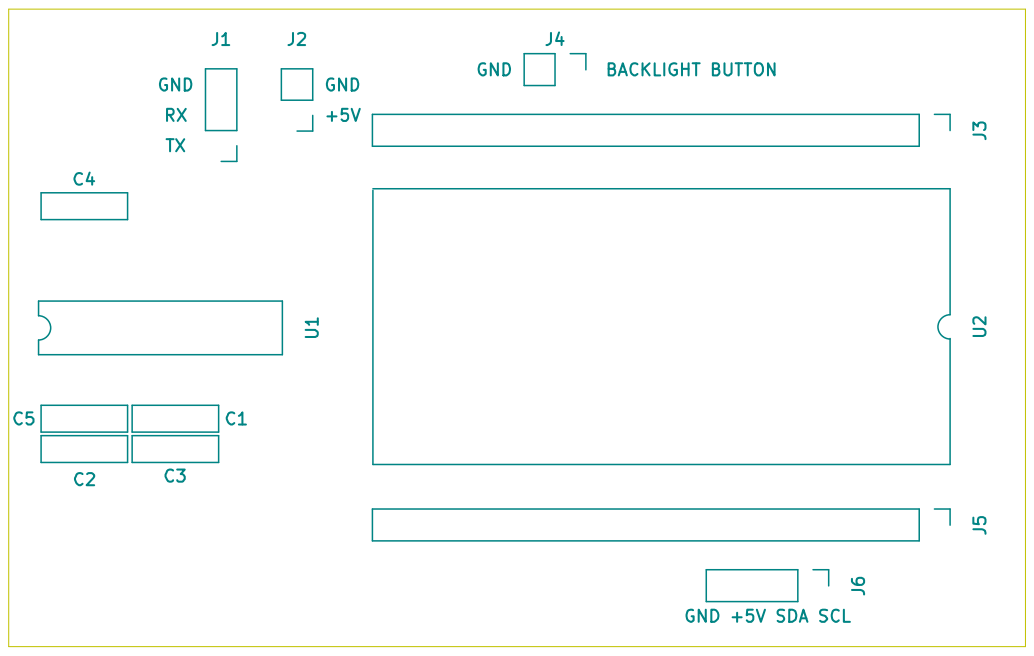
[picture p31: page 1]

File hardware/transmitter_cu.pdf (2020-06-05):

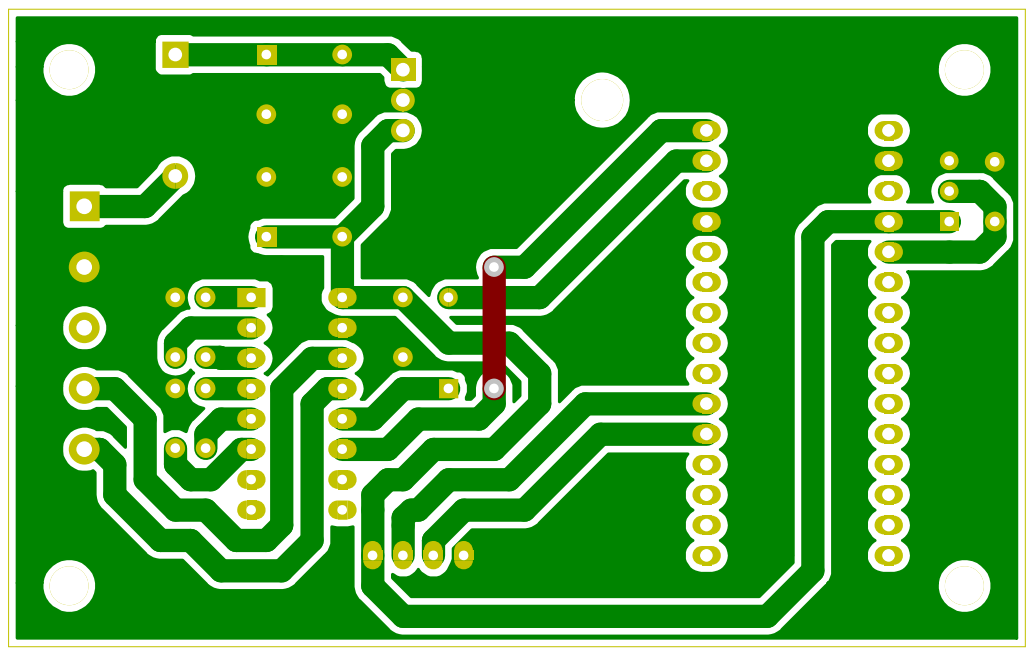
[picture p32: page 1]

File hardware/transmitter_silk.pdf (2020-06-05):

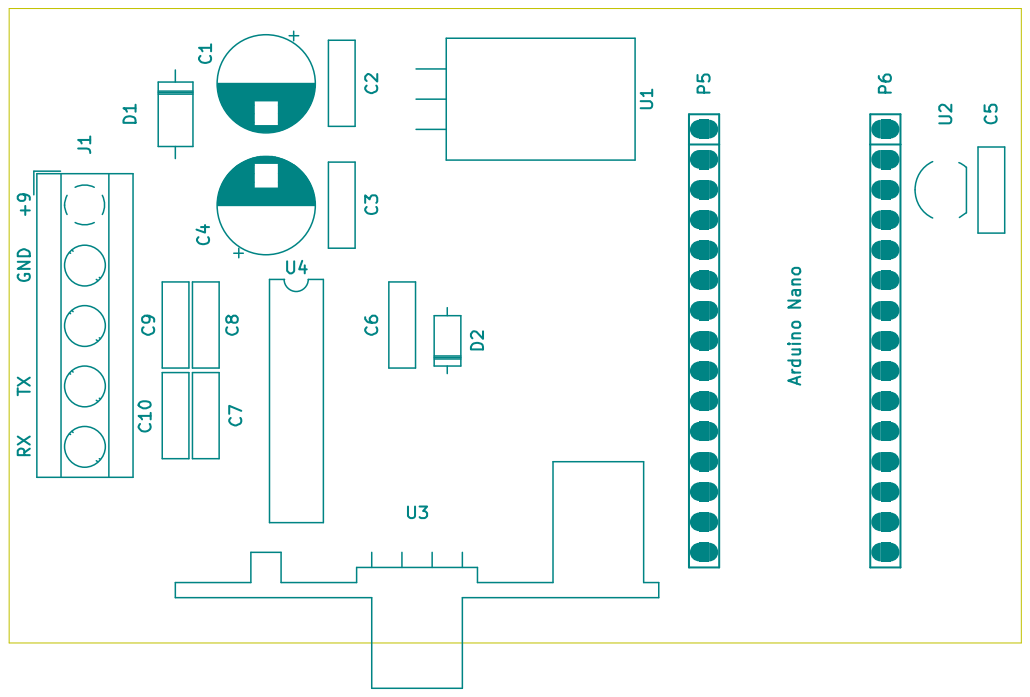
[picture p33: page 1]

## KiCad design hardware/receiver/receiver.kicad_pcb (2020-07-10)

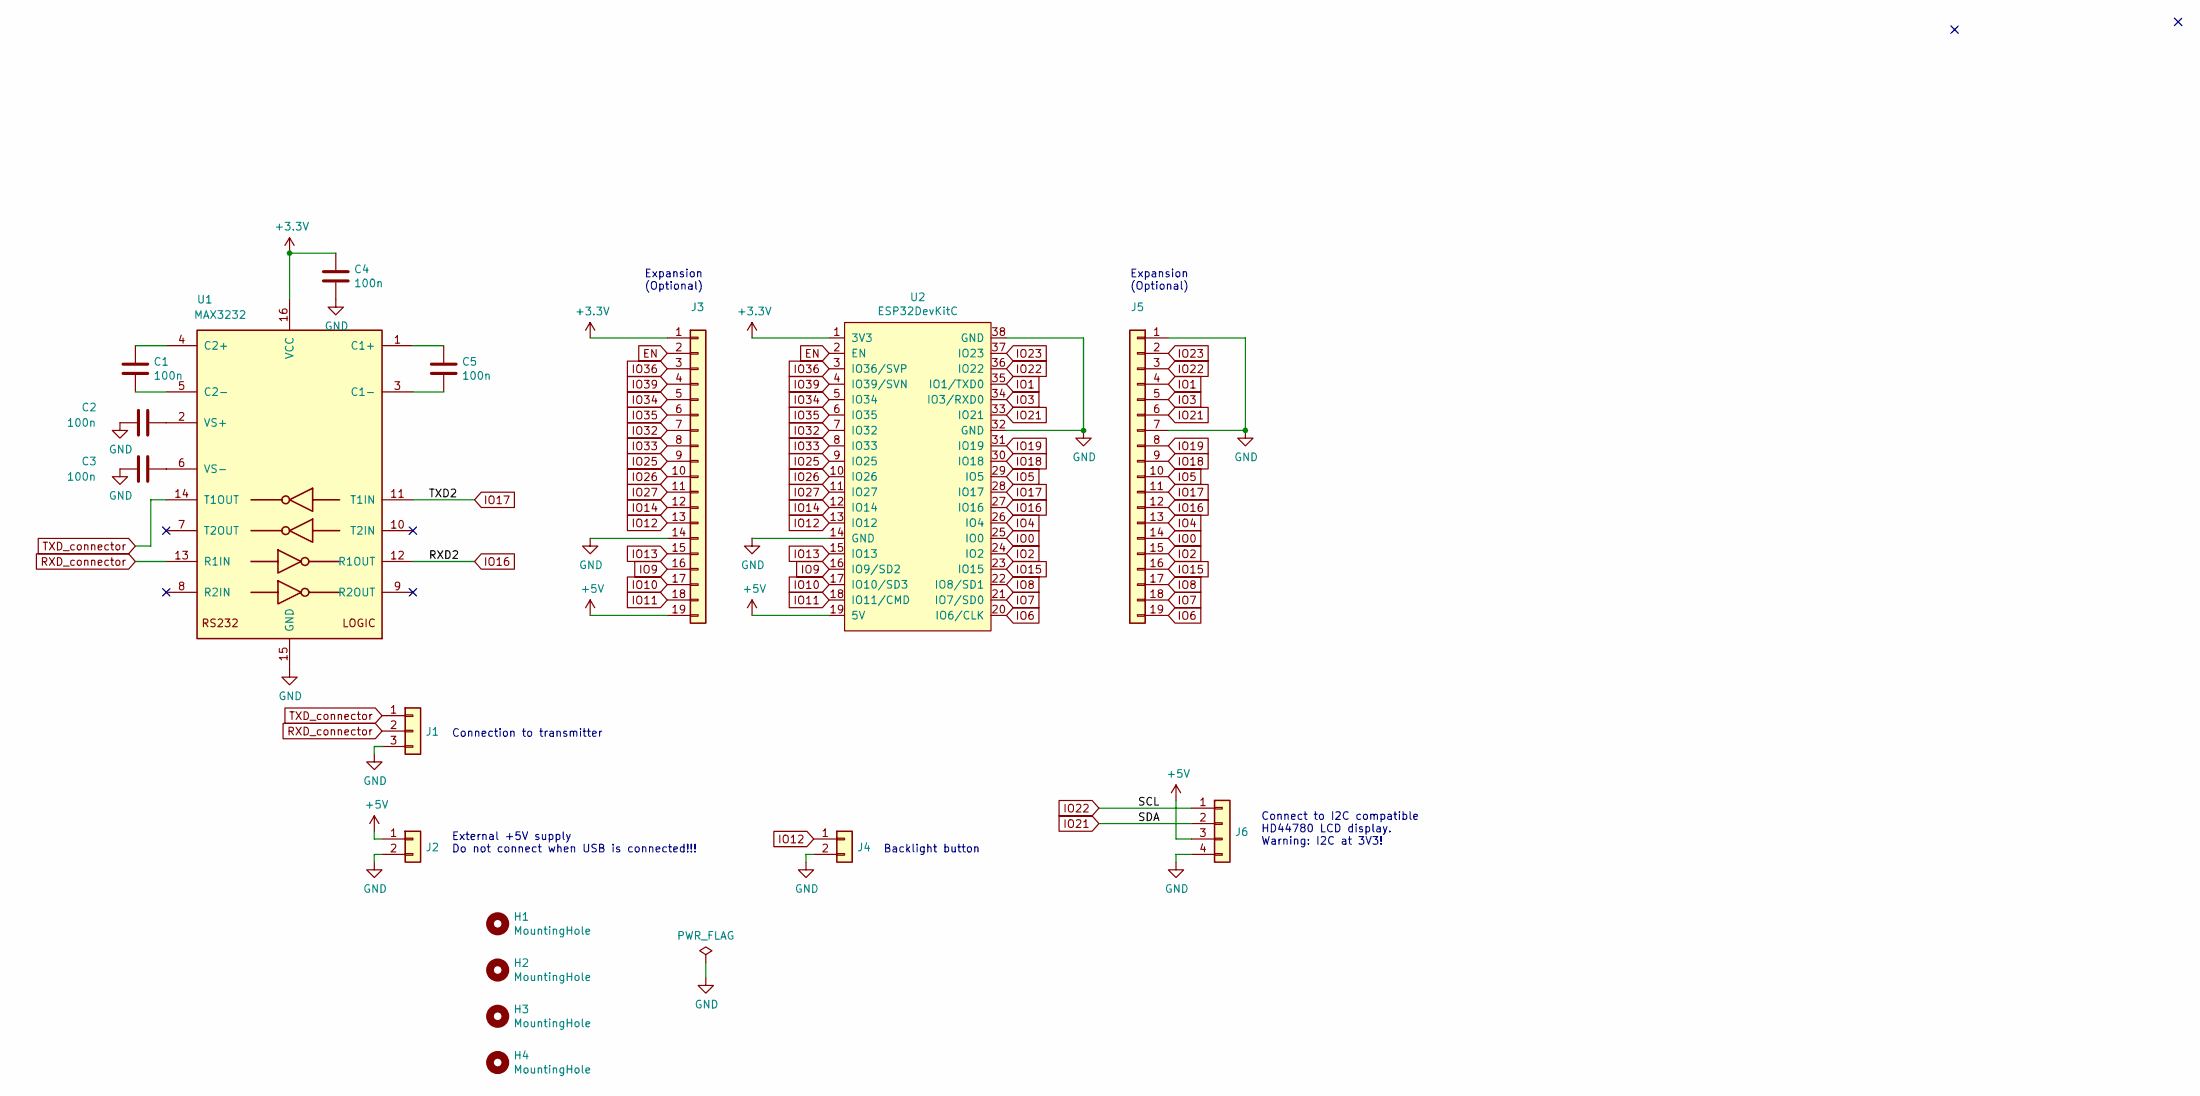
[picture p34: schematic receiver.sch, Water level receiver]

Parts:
C1, C2, C3, C4, C5: 100n; C_Rect_L7.0mm_W2.0mm_P5.00mm
H1, H2, H3, H4: MountingHole; MountingHole_3.2mm_M3
J1: Conn_01x03; PinHeader_1x03_P2.54mm_Vertical
J2, J4: Conn_01x02; PinHeader_1x02_P2.54mm_Vertical
J3, J5: Conn_01x19; PinHeader_1x19_P2.54mm_Vertical
J6: Conn_01x04; PinHeader_1x04_P2.54mm_Vertical
U1: MAX3232; DIP-16_W7.62mm_LongPads
U2: ESP32DevKitC; DIP-38_W25.4mm

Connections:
+3V3: C4.1, J3.1, U1.16 (VCC), U2.1 (3V3)
+5V: J2.1, J3.19, J6.3, U2.19 (5V)
EN: J3.2, U2.2 (EN)
GND: C2.2, C3.2, C4.2, J1.3, J2.2, J3.14, J4.2, J5.1, J5.7, J6.4, U1.15 (GND), U2.14 (GND), U2.32 (GND), U2.38 (GND)
IO0: J5.14, U2.25 (IO0)
IO1: J5.4, U2.35 (IO1/TXD0)
IO2: J5.15, U2.24 (IO2)
IO3: J5.5, U2.34 (IO3/RXD0)
IO4: J5.13, U2.26 (IO4)
IO5: J5.10, U2.29 (IO5)
IO6: J5.19, U2.20 (IO6/CLK)
IO7: J5.18, U2.21 (IO7/SD0)
IO8: J5.17, U2.22 (IO8/SD1)
IO9: J3.16, U2.16 (IO9/SD2)
IO10: J3.17, U2.17 (IO10/SD3)
IO11: J3.18, U2.18 (IO11/CMD)
IO12: J3.13, J4.1, U2.13 (IO12)
IO13: J3.15, U2.15 (IO13)
IO14: J3.12, U2.12 (IO14)
IO15: J5.16, U2.23 (IO15)
IO16: J5.12, U1.12 (R1OUT), U2.27 (IO16)
IO17: J5.11, U1.11 (T1IN), U2.28 (IO17)
IO18: J5.9, U2.30 (IO18)
IO19: J5.8, U2.31 (IO19)
IO21: J5.6, J6.2, U2.33 (IO21)
IO22: J5.3, J6.1, U2.36 (IO22)
IO23: J5.2, U2.37 (IO23)
IO25: J3.9, U2.9 (IO25)
IO26: J3.10, U2.10 (IO26)
IO27: J3.11, U2.11 (IO27)
IO32: J3.7, U2.7 (IO32)
IO33: J3.8, U2.8 (IO33)
IO34: J3.5, U2.5 (IO34)
IO35: J3.6, U2.6 (IO35)
IO36: J3.3, U2.3 (IO36/SVP)
IO39: J3.4, U2.4 (IO39/SVN)
unnamed: C1.1, U1.4 (C2+)
unnamed: C1.2, U1.5 (C2-)
unnamed: C2.1, U1.2 (VS+)
unnamed: C3.1, U1.6 (VS-)
unnamed: C5.1, U1.1 (C1+)
unnamed: C5.2, U1.3 (C1-)
RXD_connector: J1.2, U1.13 (R1IN)
TXD_connector: J1.1, U1.14 (T1OUT)

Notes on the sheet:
Connect to I2C compatible HD44780 LCD display. Warning: I2C at 3V3!
External +5V supply Do not connect when USB is connected!!!
Connection to transmitter
Expansion (Optional)
Backlight button

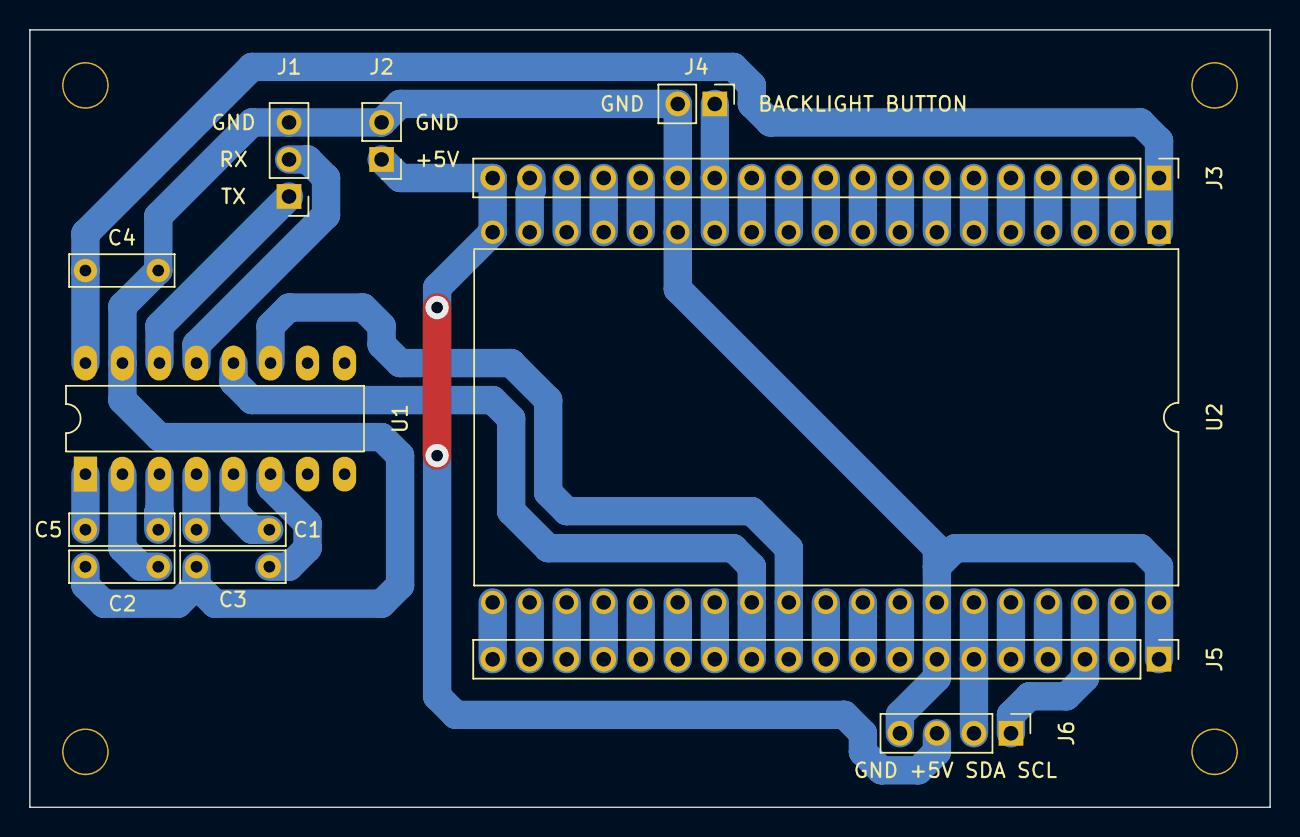
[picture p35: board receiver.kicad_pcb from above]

Board: 2 copper layers, 85.1 x 53.3 mm, 17 parts (0 on the bottom side), 43 nets.

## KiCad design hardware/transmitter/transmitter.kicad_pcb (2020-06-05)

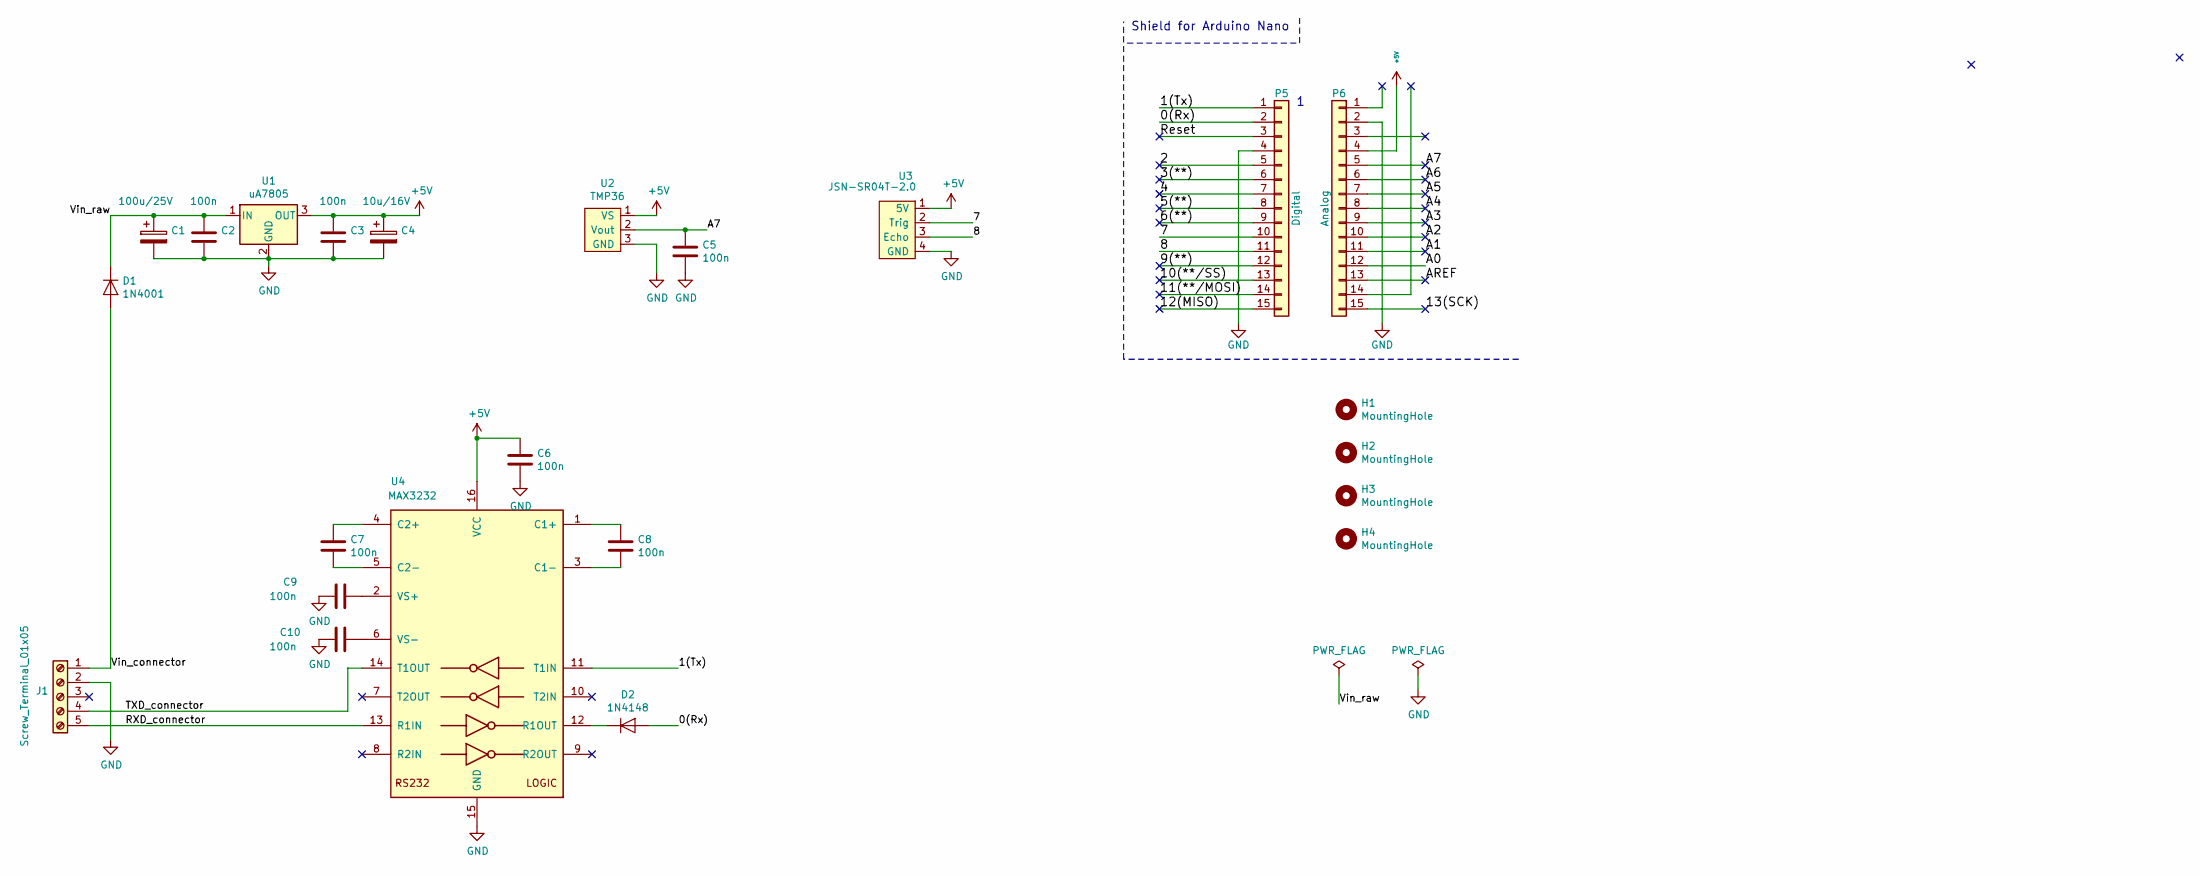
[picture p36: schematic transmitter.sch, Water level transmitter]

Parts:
C1: 100u/25V; CP_Radial_D8.0mm_P5.00mm
C2, C3, C5, C6, C7, C8, C9, C10: 100n; C_Rect_L7.0mm_W2.0mm_P5.00mm
C4: 10u/16V; CP_Radial_D8.0mm_P5.00mm
D1: 1N4001; D_DO-41_SOD81_P10.16mm_Horizontal
D2: 1N4148; D_DO-35_SOD27_P7.62mm_Horizontal
H1, H2, H3, H4: MountingHole; MountingHole_3.2mm_M3
J1: Screw_Terminal_01x05; TerminalBlock_MetzConnect_Type101_RT01605HBWC_1x05_P5.08mm_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
P5: Digital; Socket_Strip_Arduino_1x15
P6: Analog; Socket_Strip_Arduino_1x15
U1: uA7805; TO-220-3_Horizontal_TabDown
U2: TMP36; TO-92
U3: JSN-SR04T-2.0; JSN-SR04T-2.0-Vertical
U4: MAX3232; DIP-16_W7.62mm_LongPads

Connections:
+5V: C3.1, C4.1, C6.1, P6.4, U1.3 (OUT), U2.1 (VS), U3.1 (5V), U4.16 (VCC)
/0(Rx): D2.2 (A), P5.2
/1(Tx): P5.1, U4.11 (T1IN)
/2: P5.5
/3(**): P5.6
/4: P5.7
/5(**): P5.8
/6(**): P5.9
/7: P5.10, U3.2 (Trig)
/8: P5.11, U3.3 (Echo)
/9(**): P5.12
/10(**/SS): P5.13
/11(**/MOSI): P5.14
/12(MISO): P5.15
/13(SCK): P6.15
/A0: P6.12
/A1: P6.11
/A2: P6.10
/A3: P6.9
/A4: P6.8
/A5: P6.7
/A6: P6.6
/A7: C5.1, P6.5, U2.2 (Vout)
/AREF: P6.13
/RXD_connector: J1.5, U4.13 (R1IN)
/Reset: P5.3
/TXD_connector: J1.4, U4.14 (T1OUT)
/Vin_connector: D1.2 (A), J1.1
/Vin_raw: C1.1, C2.1, D1.1 (K), U1.1 (IN)
GND: C1.2, C2.2, C3.2, C4.2, C5.2, C6.2, C9.2, C10.2, J1.2, P5.4, P6.2, U1.2 (GND), U2.3 (GND), U3.4 (GND), U4.15 (GND)
unnamed: C7.1, U4.4 (C2+)
unnamed: C7.2, U4.5 (C2-)
unnamed: C8.1, U4.1 (C1+)
unnamed: C8.2, U4.3 (C1-)
unnamed: C9.1, U4.2 (VS+)
unnamed: C10.1, U4.6 (VS-)
unnamed: D2.1 (K), U4.12 (R1OUT)

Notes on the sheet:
Shield for Arduino Nano

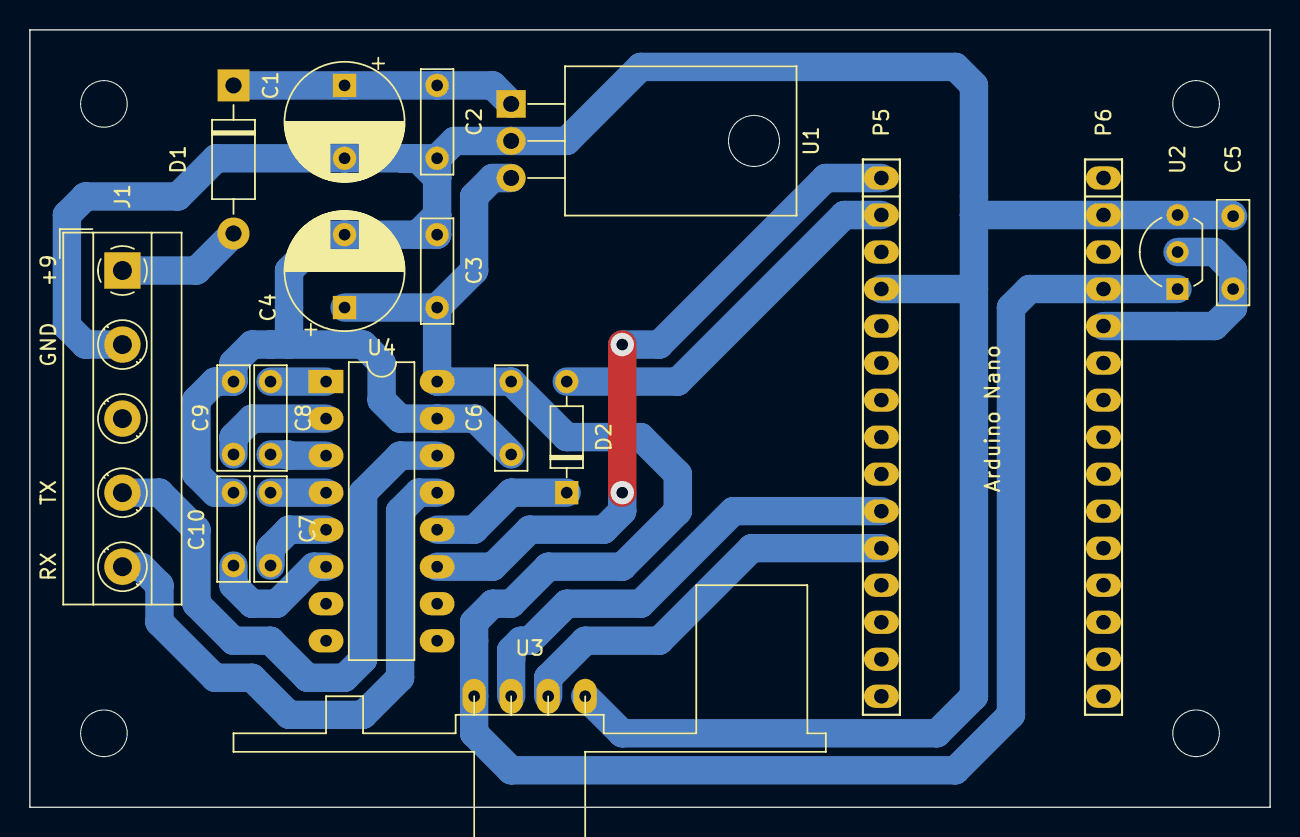
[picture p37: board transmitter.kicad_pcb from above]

Board: 2 copper layers, 85.1 x 53.3 mm, 23 parts (0 on the bottom side), 18 nets.

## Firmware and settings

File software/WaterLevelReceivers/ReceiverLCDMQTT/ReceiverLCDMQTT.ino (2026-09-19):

/*!
 * @file RecieverLCDMQTT.ino
 *
 * Read out the WaterLevelTransmitter connected on Serial2 and publish the values on:
 * - a character-based LCD display using the hd44780 chip
 * - MQTT, to a topic defined in STATE_TOPIC; note that Home Assistant discovery is supported
 *
 * Required libraries:
 * - ArduinoJson by Benoit Blanchon, 7.4.3
 * - hd44780 by Bill Perry, 1.3.2
 * - EspMQTTClient by Patrick Lapointe, 1.13.3 (with dependency PubSubLient)
 *
 * About library EspMQTTClient latest version (1.13.3) by Patrick Lapointe:
 *   It contains a compatibility issue w.r.t. Espressif Systems board manager 3.x
 *   Solution according to https://forum.arduino.cc/t/broken-dependencies/1266624/10 is working:
 *     Open on Windows c:\Users\<you>\Documents\Arduino\libraries\EspMQTTClient\src\EspMQTTClient.h
 *     or on Linux: /home/<you>/Arduino/libraries/EspMQTTClient/src/EspMQTTClient.h
 *     Change this:
 *       #else // for ESP32
 *         #include <WiFiClient.h>
 *     into this:
 *       #else // for ESP32
 *         #include <WiFi.h>
 *         #include <WiFiClient.h>
 *
 * Tested on an ESP32 DevKitC (Espressif).
 *
 * Latest tested version (built on Windows):
 * - Build on Arduino IDE 2.3.10
 * - Using esp32 by Espressif Systems board manager 3.3.10, selected board: ESP32 Dev Module
 * - With libraries (copied from verbose compile output)
 *   Using library ArduinoJson at version 7.4.3 in folder: C:\Users\marti\Documents\Arduino\libraries\ArduinoJson 
 *   Using library Wire at version 3.3.10 in folder: C:\Users\marti\AppData\Local\Arduino15\packages\esp32\hardware\esp32\3.3.10\libraries\Wire 
 *   Using library hd44780 at version 1.3.2 in folder: C:\Users\marti\Documents\Arduino\libraries\hd44780 
 *   Using library EspMQTTClient at version 1.13.3 in folder: C:\Users\marti\Documents\Arduino\libraries\EspMQTTClient 
 *   Using library ArduinoOTA at version 3.3.10 in folder: C:\Users\marti\AppData\Local\Arduino15\packages\esp32\hardware\esp32\3.3.10\libraries\ArduinoOTA 
 *   Using library Networking at version 3.3.10 in folder: C:\Users\marti\AppData\Local\Arduino15\packages\esp32\hardware\esp32\3.3.10\libraries\Network 
 *   Using library Update at version 3.3.10 in folder: C:\Users\marti\AppData\Local\Arduino15\packages\esp32\hardware\esp32\3.3.10\libraries\Update 
 *   Using library PubSubClient at version 2.8 in folder: C:\Users\marti\Documents\Arduino\libraries\PubSubClient 
 *   Using library WiFi at version 3.3.10 in folder: C:\Users\marti\AppData\Local\Arduino15\packages\esp32\hardware\esp32\3.3.10\libraries\WiFi 
 *   Using library WebServer at version 3.3.10 in folder: C:\Users\marti\AppData\Local\Arduino15\packages\esp32\hardware\esp32\3.3.10\libraries\WebServer 
 *   Using library FS at version 3.3.10 in folder: C:\Users\marti\AppData\Local\Arduino15\packages\esp32\hardware\esp32\3.3.10\libraries\FS 
 *   Using library ESPmDNS at version 3.3.10 in folder: C:\Users\marti\AppData\Local\Arduino15\packages\esp32\hardware\esp32\3.3.10\libraries\ESPmDNS 
 *   Using library Hash at version 3.3.10 in folder: C:\Users\marti\AppData\Local\Arduino15\packages\esp32\hardware\esp32\3.3.10\libraries\Hash
 *
 * Latest test version (build on Linux):
 * - Build on Arduino IDE 2.3.10
 * - Using esp32 by Espressif Systems board manager 3.3.11, selected board: ESP32 Dev Module
 * - With libraries (copied from verbose compile output)
 *   Using library ArduinoJson at version 7.4.3 in folder: /home/martin/Arduino/libraries/ArduinoJson 
 *   Using library Wire at version 3.3.11 in folder: /home/martin/.arduino15/packages/esp32/hardware/esp32/3.3.11/libraries/Wire 
 *   Using library hd44780 at version 1.3.2 in folder: /home/martin/Arduino/libraries/hd44780 
 *   Using library EspMQTTClient at version 1.13.3 in folder: /home/martin/Arduino/libraries/EspMQTTClient 
 *   Using library ArduinoOTA at version 3.3.11 in folder: /home/martin/.arduino15/packages/esp32/hardware/esp32/3.3.11/libraries/ArduinoOTA 
 *   Using library Networking at version 3.3.11 in folder: /home/martin/.arduino15/packages/esp32/hardware/esp32/3.3.11/libraries/Network 
 *   Using library Update at version 3.3.11 in folder: /home/martin/.arduino15/packages/esp32/hardware/esp32/3.3.11/libraries/Update 
 *   Using library PubSubClient at version 2.8 in folder: /home/martin/Arduino/libraries/PubSubClient 
 *   Using library WiFi at version 3.3.11 in folder: /home/martin/.arduino15/packages/esp32/hardware/esp32/3.3.11/libraries/WiFi 
 *   Using library WebServer at version 3.3.11 in folder: /home/martin/.arduino15/packages/esp32/hardware/esp32/3.3.11/libraries/WebServer 
 *   Using library FS at version 3.3.11 in folder: /home/martin/.arduino15/packages/esp32/hardware/esp32/3.3.11/libraries/FS 
 *   Using library ESPmDNS at version 3.3.11 in folder: /home/martin/.arduino15/packages/esp32/hardware/esp32/3.3.11/libraries/ESPmDNS 
 *   Using library Hash at version 3.3.11 in folder: /home/martin/.arduino15/packages/esp32/hardware/esp32/3.3.11/libraries/Hash 
 *
 * @author Martin Vanbrabant
 */

// Create your own secrets.h (mine is not in the repository), based on secrets_example.h
#include "secrets.h"

#include <ArduinoJson.h> // see https://arduinojson.org/v7/. This is not <Arduino_JSON.h>

#include <Wire.h>
#include <hd44780.h>                       // main hd44780 header
#include <hd44780ioClass/hd44780_I2Cexp.h> // i2c expander i/o class header
#include "LCDbarGraph.h"

#include <EspMQTTClient.h>

// 1: debug output (general) on serial, 0: no debug output (general)
#define DEBUG 0
// 1: debug output (MQTT) on serial, 0: no debug output (MQTT)
#define DEBUG_MQTT 1
// 1: start by processing some fake input, 0: no fake input
#define DEBUG_FAKE_INPUT 0

// IO pins
#define BACKLIGHT_BUTTON_IOPIN 12

// LCD info
#define LCD_ADDR 0x27
#define LCD_COLS 16
#define LCD_ROWS 2
#define LCD_BAR_X 0
#define LCD_BAR_Y 0
#define LCD_BAR_L 16
#define LCD_PERCENT_VALUE_X 0
#define LCD_PERCENT_VALUE_Y 1
#define LCD_LOW_VALUE_X 5
#define LCD_LOW_VALUE_Y 1
#define LCD_L_VALUE_X 9
#define LCD_L_VALUE_Y 1
#define LCD_HEARTBEAT_X 15
#define LCD_HEARTBEAT_Y 1

// An LCD device is connected via I2C, the I2C address is known,
// so using this constructor of this derived class.
hd44780_I2Cexp lcd(LCD_ADDR);

// The bar graph to display the percentage
LCDbarGraph barGraph(lcd, LCD_BAR_X, LCD_BAR_Y, LCD_BAR_L, 0, 100);

// The status of the backlight
bool backlightOn;

// Timing - everything unsigned long, milliseconds
#define INITIAL_SERIAL2_DELAY 1000ul
#define INITIAL_TRIGGER_DELAY 15000ul
#define TRIGGER_INTERVAL 1000ul
#define MQTT_INTERVAL 60000ul
#define BUTTON_DEBOUNCE_DELAY 100ul

// The measurements to publish
double measuredTDegreesCelcius;   // temperature in degrees Celcius
double measuredTDegreesCelcius1;  // temperature in degrees Celcius, rounded to one digit after the decimal point
double measuredVolumeLiter;       // volume in litres
int    measuredVolumeLiterInt;    // volume in litres, integer
double measuredVolumePercent;     // volume as a percentage
int    measuredVolumePercentInt;  // volume as a percentage, integer
bool   measuredLowBool;           // low indicator

// MQTT configuration
constexpr uint16_t MY_MQTT_MAX_PACKET_SIZE = 1024;
constexpr char DEVICE_ID[] = "regenput_monitor";
constexpr char DEVICE_NAME[] = "Regenput";
constexpr char MANUFACTURER[] = "Martin Vanbrabant";
constexpr char MODEL[] = "ESP32 Regenputmeter";
constexpr char STATE_TOPIC[] = "home/regenput/state";
constexpr char AVAILABILITY_TOPIC[] = "home/regenput/availability";

EspMQTTClient mqttClient(
  SECRET_SSID,
  SECRET_WIFI_PASS,
  SECRET_MQTT_SERVER,     // MQTT Broker server ip
  SECRET_MQTT_USER,       // Can be omitted if not needed
  SECRET_MQTT_PASS,       // Can be omitted if not needed
  DEVICE_ID,              // Client name that uniquely identifies your device
  SECRET_MQTT_PORT        // The MQTT port, defaults to 1883
);

bool connected = false;

/*!
 * Preset a JSON document with the common properties for Home Assistant discovery
 */
void presetDiscovery(JsonDocument& doc)
{
  doc.clear();

  doc["availability_topic"] = AVAILABILITY_TOPIC;
  doc["payload_available"] = "online";
  doc["payload_not_available"] = "offline";

  JsonObject device = doc["device"].to<JsonObject>();
  device["name"] = DEVICE_NAME;
  device["manufacturer"] = MANUFACTURER;
  device["model"] = MODEL;
  JsonArray ids = device["identifiers"].to<JsonArray>();
  ids.add(DEVICE_ID);
}

/*!
 * Publish Home Assistant discovery for a component
 */
void publishComponentDiscovery(const char* component, const char* objectId, JsonDocument& doc)
{
  String payload;
  serializeJson(doc, payload);
  String topic = String("homeassistant/") + component + "/" + objectId + "/config";
#if DEBUG == 1
  Serial.print("Publishing discovery to topic: ");
  Serial.println(topic);
  Serial.print("Payload: ");
  Serial.println(payload);
#endif

  if (!mqttClient.publish(topic.c_str(), payload.c_str(), true /* retain */)) {
#if DEBUG_MQTT == 1
    Serial.print("MQTT publishing failed for topic: ");
    Serial.println(topic);
#endif
    return;
  }
}

/*!
 * Publish all discovery configuration messages for Home Assistant discovery
 */
void publishDiscovery()
{
  JsonDocument doc;

  presetDiscovery(doc);
  doc["name"] = "Temperatuur";
  doc["unique_id"] = "regenput_temperatuur";
  doc["state_topic"] = STATE_TOPIC;
  doc["unit_of_measurement"] = "°C";
  doc["device_class"] = "temperature";
  doc["state_class"] = "measurement";
  doc["value_template"] = "{{ value_json.t_C }}";
  publishComponentDiscovery("sensor", "regenput_temperatuur", doc);

  presetDiscovery(doc);
  doc["name"] = "Volume";
  doc["unique_id"] = "regenput_volume";
  doc["state_topic"] = STATE_TOPIC;
  doc["unit_of_measurement"] = "liter";
  doc["state_class"] = "measurement";
  doc["value_template"] = "{{ value_json.vol_l }}";
  publishComponentDiscovery("sensor", "regenput_volume", doc);

  presetDiscovery(doc);
  doc["name"] = "Volume percent";
  doc["unique_id"] = "regenput_volume_percent";
  doc["state_topic"] = STATE_TOPIC;
  doc["unit_of_measurement"] = "%";
  doc["state_class"] = "measurement";
  doc["value_template"] = "{{ value_json.vol_percent }}";
  publishComponentDiscovery("sensor", "regenput_volume_percent", doc);

  presetDiscovery(doc);
  doc["name"] = "Volumecheck";
  doc["unique_id"] = "regenput_volume_laag";
  doc["state_topic"] = STATE_TOPIC;
  doc["payload_on"] = true;
  doc["payload_off"] = false;
  doc["value_template"] = "{{ value_json.low }}";
  doc["device_class"] = "problem";
  publishComponentDiscovery("binary_sensor", "regenput_volume_laag", doc);
}

/*!
 * This function is called once everything is connected (Wifi and MQTT)
 * WARNING : YOU MUST IMPLEMENT IT IF YOU USE EspMQTTClient
 */
void onConnectionEstablished()
{
#if DEBUG_MQTT == 1
  Serial.println("MQTT connected.");
#endif
  publishDiscovery();
  if (!mqttClient.publish(AVAILABILITY_TOPIC, "online", true)) {
#if DEBUG_MQTT == 1
    Serial.print("MQTT publishing failed for topic: ");
    Serial.println(AVAILABILITY_TOPIC);
#endif
    return;
  }
  connected = true;
}

/*!
 * Arduino's setup function
 */
void setup() {
  pinMode(BACKLIGHT_BUTTON_IOPIN, INPUT_PULLUP);

  Serial.begin(115200);
  Serial2.setPins(16, 17); // used to be default, now needed for board manager v3, see https://docs.espressif.com/projects/arduino-esp32/en/latest/migration_guides/2.x_to_3.0.html
  Serial2.begin(115200);
  unsigned long tSerial2 = millis();

  lcd.begin(LCD_COLS, LCD_ROWS);
  lcd.print("Initialising...");
  backlightOn = true;

  // be patient with serial port 2:
  // wait until initialised and then flush rubbish input
  while (millis() - tSerial2 < INITIAL_SERIAL2_DELAY) {
    // empty
  }
  while (Serial2.available() > 0 ) {
    Serial2.read();
  }

  mqttClient.setMaxPacketSize(MY_MQTT_MAX_PACKET_SIZE);

#if DEBUG_MQTT == 1
  mqttClient.enableDebuggingMessages(); // Enable debugging messages sent to serial output
#endif

  mqttClient.enableLastWillMessage(AVAILABILITY_TOPIC, "offline", true);
}

/*!
 * Arduino's loop function
 */
void loop() {
  mqttClient.loop();
#if DEBUG_FAKE_INPUT == 0
  handleTransmitter();
#else
  handleFakeInput();
#endif
  handleButtons();
}

/*!
 * Interact with the WaterLevelTransmitter
 */
void handleTransmitter() {
  static bool first = true;
  static unsigned long tPrev = 0;
  static uint8_t iInputBuffer = 0;
  static char inputBuffer[256];
  unsigned long tNow;

  if (first) {
    // ignore the response of the transmitter to initial uncontrolled output on our Serial2
    while (Serial2.available() > 0) {
      Serial2.read();
    }
    // first trigger?
    tNow = millis();
    if (tNow - tPrev >= INITIAL_TRIGGER_DELAY) {
      Serial2.print("?");
      first = false;
      tPrev = tNow;
    }
  } else {
    // handle the response of the transmitter
    while (Serial2.available() > 0) {
      char c;
      c = Serial2.read();
      if (iInputBuffer == 0) {
        if (c == '{') {
          inputBuffer[iInputBuffer++] = c;
        }
      } else if (iInputBuffer < sizeof(inputBuffer) - 1) {
        inputBuffer[iInputBuffer++] = c;
        if (c == '}') {
          inputBuffer[iInputBuffer] = '\0';
          consume(inputBuffer);
          iInputBuffer = 0;
        }
      } else {
        // oops, avoid buffer overflow
        iInputBuffer = 0;
      }
    }
    // next trigger?
    tNow = millis();
    if (tNow - tPrev >= TRIGGER_INTERVAL) {
      Serial2.print("?");
      tPrev = tNow;
    }
  }
}

#if DEBUG_FAKE_INPUT == 1
/*!
 * Replacement for handleTransmitter() for debugging; useful to test if not connected to the transmitter
 */
void handleFakeInput() {
  static const char * fakeInput[] = {
    "{\"t_C\": -15.00, \"distance_m\": 2.130, \"height_m\": 0.000, \"vol_l\":    0, \"vol_percent\":   0.00, \"low\":  true}",
    "{\"t_C\": -10.00, \"distance_m\": 1.980, \"height_m\": 0.150, \"vol_l\":  300, \"vol_percent\":  10.00, \"low\":  true}",
    "{\"t_C\":  -5.00, \"distance_m\": 1.830, \"height_m\": 0.300, \"vol_l\":  600, \"vol_percent\":  20.00, \"low\": false}",
    "{\"t_C\":   0.00, \"distance_m\": 1.680, \"height_m\": 0.450, \"vol_l\":  900, \"vol_percent\":  30.00, \"low\": false}",
    "{\"t_C\":   5.00, \"distance_m\": 1.530, \"height_m\": 0.600, \"vol_l\": 1200, \"vol_percent\":  40.00, \"low\": false}",
    "{\"t_C\":  10.00, \"distance_m\": 1.380, \"height_m\": 0.750, \"vol_l\": 1500, \"vol_percent\":  50.00, \"low\": false}",
    "{\"t_C\":  15.00, \"distance_m\": 1.230, \"height_m\": 0.900, \"vol_l\": 1800, \"vol_percent\":  60.00, \"low\": false}",
    "{\"t_C\":  20.00, \"distance_m\": 1.080, \"height_m\": 1.050, \"vol_l\": 2100, \"vol_percent\":  70.00, \"low\": false}",
    "{\"t_C\":  21.00, \"distance_m\": 0.930, \"height_m\": 1.200, \"vol_l\": 2400, \"vol_percent\":  80.00, \"low\": false}",
    "{\"t_C\":  21.50, \"distance_m\": 0.780, \"height_m\": 1.350, \"vol_l\": 2700, \"vol_percent\":  90.00, \"low\": false}",
    "{\"t_C\":  21.78, \"distance_m\": 0.630, \"height_m\": 1.500, \"vol_l\": 3000, \"vol_percent\": 100.00, \"low\": false}"
};
  static int i = 0;
  static int j = 0;
  static unsigned long tPrev = 0;
  unsigned long tNow;

  if (i < 600) {
    tNow = millis();
    if (tNow - tPrev >= TRIGGER_INTERVAL) {
      consume(fakeInput[j]);
      if (j < sizeof(fakeInput)/sizeof(fakeInput[0]) - 1) {
        j++;
      }
      i++;
      tPrev = tNow;
    }
  }
}
#endif

/*!
 * Consume one collected input string
 *
 * @param inputString the collected JSON string
 */
void consume(const char * inputString) {
  static bool first = true;
  static double smoothedLow;

#if DEBUG == 1
  Serial.println(millis());
  Serial.println(inputString);
#endif

  JsonDocument doc;
  DeserializationError error = deserializeJson(doc, inputString);
  if (error) {
#if DEBUG == 1
    Serial.println("Unexpected input skipped.");
#endif
    return;
  }

  double tDegreesCelcius = doc["t_C"];
  double volumeLiter = doc["vol_l"];
  double volumePercent = doc["vol_percent"];
  bool low = doc["low"];
  smooth(measuredTDegreesCelcius, tDegreesCelcius, first);
  smooth(measuredVolumeLiter,     volumeLiter,     first);
  smooth(measuredVolumePercent,   volumePercent,   first);
  smooth(smoothedLow,             (double)low,     first);
  first = false;
  measuredTDegreesCelcius1 = round(measuredTDegreesCelcius * 10.0) / 10.0;
  measuredVolumeLiterInt = measuredVolumeLiter + 0.5;
  measuredVolumePercentInt = measuredVolumePercent + 0.5;
  measuredLowBool = (smoothedLow >= 0.5);

  publishOnLCD();
  publishOnMqtt();
}

/*!
 * Smooth a measurement value
 *
 * @param smoothed reference to the smoothed value (to be provided to all next calls)
 * @param raw the new measured value
 * @param first if true, this is the first measurement (previous smoothed value will not be used)
 */
void smooth(double& smoothed, double raw, bool first) {
  if (first) {
    smoothed = raw;
  } else {
    smoothed = 0.9 * smoothed + 0.1 * raw;
  }
}

/*!
 * Publish the measurements to the LCD display
 */
void publishOnLCD() {
  static bool first = true;
  static int prevVolumeLiterInt = -1;
  static int prevVolumePercentInt = -1;
  static bool prevLowBool = false;
  static const char heartBeat[] = {'*', ' '};
  static uint8_t iHeartBeat = 0;

  if (measuredVolumePercentInt != prevVolumePercentInt) {
    lcd.setCursor(LCD_PERCENT_VALUE_X, LCD_PERCENT_VALUE_Y);
    lcd.printf("%3d", measuredVolumePercentInt);
    if (first) {
      lcd.print("%");
    }
    barGraph.display(measuredVolumePercentInt);
    prevVolumePercentInt = measuredVolumePercentInt;
  }
  if (measuredLowBool != prevLowBool) {
    lcd.setCursor(LCD_LOW_VALUE_X, LCD_LOW_VALUE_Y);
    lcd.print(measuredLowBool ? "LOW" : "   ");
    prevLowBool = measuredLowBool;
  }
  if (measuredVolumeLiterInt != prevVolumeLiterInt) {
    lcd.setCursor(LCD_L_VALUE_X, LCD_L_VALUE_Y);
    lcd.printf("%5d", measuredVolumeLiterInt);
    if (first) {
      lcd.print("l");
    }
    prevVolumeLiterInt = measuredVolumeLiterInt;
  }
  lcd.setCursor(LCD_HEARTBEAT_X, LCD_HEARTBEAT_Y);
  lcd.write(heartBeat[iHeartBeat]);
  iHeartBeat = (iHeartBeat + 1) % (sizeof(heartBeat) / sizeof(heartBeat[0]));
  first = false;
}

/*!
 * Publish the measurements to MQTT
 *
 * Publishing frequency is restricted.
 *
 */
void publishOnMqtt() {
  static unsigned long tPrevWriting;
  static bool first = true;
  unsigned long tNowWriting;

  if (!connected) {
#if DEBUG_MQTT == 1
    Serial.println("MQTT not yet connected.");
#endif
    return;
  }
  tNowWriting = millis();
  if (first || (tNowWriting - tPrevWriting) >= MQTT_INTERVAL) {
    JsonDocument doc;
    doc["t_C"] = measuredTDegreesCelcius1;
    doc["vol_l"] = measuredVolumeLiterInt;
    doc["vol_percent"] = measuredVolumePercentInt;
    doc["low"] = measuredLowBool;
    String jsonString;
    serializeJson(doc, jsonString);
#if DEBUG == 1
    Serial.print("Publishing state to topic: ");
    Serial.println(STATE_TOPIC);
    Serial.print("Payload: ");
    Serial.println(jsonString);
#endif
    if (!mqttClient.publish(STATE_TOPIC, jsonString)) {
#if DEBUG_MQTT == 1
      Serial.print("MQTT publishing failed for topic: ");
      Serial.println(STATE_TOPIC);
#endif
      return;
    }

    // If we get here, the write was successful
    lcd.setCursor(LCD_HEARTBEAT_X, LCD_HEARTBEAT_Y);
    lcd.write('.');
    tPrevWriting = tNowWriting;
    first = false;
  }
}

/*!
 * Check buttons and do appropriate actions
 */
void handleButtons() {
  static unsigned long tPrevBacklight = 0;
  unsigned long tNow;
  bool pushed;

  tNow = millis();
  // control LCD backlight
  if (tNow - tPrevBacklight >= BUTTON_DEBOUNCE_DELAY) {
    pushed = (digitalRead(BACKLIGHT_BUTTON_IOPIN) == 0);
    if (pushed != backlightOn) {
      if (pushed) {
        lcd.backlight();
      } else {
        lcd.noBacklight();
      }
      tPrevBacklight = tNow;
      backlightOn = pushed;
    }
  }
}

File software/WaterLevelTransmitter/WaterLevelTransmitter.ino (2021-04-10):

/*!
 * @file WaterLevelTransmitter.ino
 *
 * Measure the water level in a reservoir with an ultrasone distance detector.
 *
 * Tested on an Arduino Nano with a JSN-SR04T-2.0 ultrasone distance detector.
 *
 * @author Martin Vanbrabant
 */

#include "Tmp36.h"
#include "UsDetector.h"

// TMP36
#define TMP36_PIN A7
#define ADC_MAXVALUE 1023
#define ADC_VOLTAGE 5.0

// JSN-SR04T-2.0
#define US_TRIGPIN 7
#define US_ECHOPIN 8
#define US_TIMEOUT 100000ul // microseconds; note JSN-SR04T 2.0 limits to 38 ms automatically

Tmp36 tmp = Tmp36(TMP36_PIN, ADC_MAXVALUE, ADC_VOLTAGE);
UsDetector det = UsDetector(US_TRIGPIN, US_ECHOPIN, US_TIMEOUT);

// --- Dimensions
// H1 (meter)
#define H1 1.50
// H2 (meter)
#define H2 0.68
// H3 (meter)
#define H3 0.12
// V (liter)
#define V 3000
// X_MIN (meter)
#define X_MIN 0.25

float temperature;
float distance;
float height;
float volume;
float percent;

//JSON string
const char *json_part1 =
  "{\n"
  "  \"t_C\": ";
const char *json_part2 = ",\n"
  "  \"distance_m\": ";
const char *json_part3 = ",\n"
  "  \"height_m\": ";
const char *json_part4 = ",\n"
  "  \"vol_l\": ";
const char *json_part5 = ",\n"
  "  \"vol_percent\": ";
const char *json_part6 = ",\n"
  "  \"low\": ";
const char *json_part7 = "\n"
  "}";

void print_json() {
  Serial.print(json_part1);
  Serial.print(temperature, 2);
  Serial.print(json_part2);
  Serial.print(distance, 3);
  Serial.print(json_part3);
  Serial.print(height, 3);
  Serial.print(json_part4);
  Serial.print(volume, 0);
  Serial.print(json_part5);
  Serial.print(percent, 2);
  Serial.print(json_part6);
  Serial.print(height < X_MIN ? "true" : "false");
  Serial.println(json_part7);
}

void setup() {
  Serial.begin(115200);
  det.begin();
}

void loop() {
  if (Serial.available()) {
    temperature = tmp.measureTemperature();
    distance = det.measureDistance(temperature);
    height = (H1 + H2 - H3) - distance;
    if (height < 0) {
      height = 0;
    } else if (height > H1) {
      height = H1;
    }
    volume = height / H1 * V;
    percent = height / H1 * 100.0;
    print_json();
    Serial.read();
    delay(100);
  }
}

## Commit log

2020-03-03 first commit of transmitter
    [transmitter.kicad_pcb, transmitter.sch]
2020-03-03 added copper zone
    [transmitter.kicad_pcb]
2020-03-07 added plot_files
    [transmitter-B_Cu.gbr, transmitter-B_Mask.gbr, transmitter-F_Cu.gbr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]
2020-03-09 copper zone reviewed (clearance, minimum with, solid pad connection)
    [transmitter-B_Cu.gbr, transmitter-B_Mask.gbr, transmitter-Edge_Cuts.gbr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]
2020-04-27 pcb narrowed by 5 mm
    [transmitter-B_Cu.gbr, transmitter-B_Mask.gbr, transmitter-Edge_Cuts.gbr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]
2020-05-24 resized board to 85,090 mm x 53,340 mm
    [transmitter-B_Cu.gbr, transmitter-B_Mask.gbr, transmitter-Edge_Cuts.gbr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]
2020-05-30 Add GCode files for LinuxCNC PCB milling and PCB sticker
    [transmitter-B_Cu.gbr, transmitter-B_Mask.gbr, transmitter-Edge_Cuts.gbr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]
2020-06-05 improved silk + additional .pdfs
    [transmitter.kicad_pcb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]
2020-06-25 lessons learned: temperature measurement (solution)
2020-06-25 lessons learned: temperature measurement (pictures)
2020-06-25 lessons learned: temperature measurement
2020-07-04 added backlight button
2020-07-10 added receiver
    [receiver-B_Cu.gbr, receiver-B_Mask.gbr, receiver-Edge_Cuts.gbr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]
2020-08-09 ADD: receiver PCB, connections transmitter-receiver
2020-11-10 ADD: current issue 1.
2020-11-10 UPD: current issue 1.
2021-01-02 ADD: doc: Node-RED flow MQTT --> ThingSpeak
2021-04-05 update current issue 1
2021-04-10 new H3 after changing position of sensor
2021-11-10 Update README.md
    https://forum.kicad.info/t/warning-avoid-all-links-to-kicad-pcb-org-use-kicad-org/31521
2022-05-13 condensation on the sensor: from current issue to lesson learned
2024-08-22 build with Arduino IDE 2.3.2 and esp32 board manager 3.0.3
2026-06-08 version bump of Arduino IDE and esp32 board manager/libraries
